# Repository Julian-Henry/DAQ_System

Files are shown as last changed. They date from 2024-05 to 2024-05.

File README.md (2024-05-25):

# DAQ_System

# Project Showcase Link
https://eecs.engineering.oregonstate.edu/project-showcase/projects/?id=z2oxjPZD8s8oi1AW

# Project Overview
The purpose of the personal data acquisition prototype project is to design a data recorder prototype for a general consumer target market. This prototype was designed to be used with a go-kart. Sensors can be connected to the data recorder in a modular fashion. Sensor modules were developed on custom-designed PCBs that utilize STM32 microcontrollers. Each microcontroller sends data to a database hosted on a Raspberry Pi. The data can then be outputted to the user through an intuitive UI. The firmware for the microcontrollers was developed using the RUST programming language. The database used SQLite. The UI was made using the EGUI framework in RUST. Some notable achievements include the UI and firmware development using Rust, a cutting-edge secure programming language, and the modularity of the system which allows for a variety of sensor configurations based on the user's preferences. Key challenges revolved around the creation of custom STM32-based PCBs, suggesting one key area for future improvement.

## System setup guide

Materials: 
  - Raspberry Pi with monitor, keyboard, and mouse. Make sure Its micro SD card has more than 8GB of space

  - RS485 CAN Hat

  - “Sensor modules” 

.

Steps:

1. Use the RS485 CAN Hat on the Pi. Connect sensor modules.

2. Flash code to the Nucleo dev boards that are in charge of the sensors (files in the nucleo_firmware directory).

3. Set up the CAN Hat on the Pi:

  // Open the Raspberry Pi terminal and run the following commands:
  wget https://github.com/joan2937/lg/archive/master.zip 
  unzip master.zip
  cd lg-master
  sudo make install
  
  sudo apt-get update
  sudo apt-get install python-serial
  sudo pip install python-can 
    //if it gives an error, run: rm /usr/lib/python3.11/EXTERNALLY-MANAGED
  sudo nano /boot/config.txt
  //in the file, Modify/create:
  dtparam=spi=on
  dtoverlay=mcp2515-can0,oscillator=12000000,interrupt=25,spimaxfrequency=2000000

  sudo reboot  //NOTE: you have to have the CAN hat connected before the Pi reboots
  
  //Finally, test that it knows the CAN is there:
  	dmesg | grep -i '\(can\|spi\)'

4. Copy the daq_gui_1 & logger_code directories to the Pi

5. Run the pi_can.py file in the logger_code directory to start the communication. You should see the data being sent in the terminal if it is working.

6. Go to the daq_gui_1 directory and run the daq_gui code (Use cargo run --release if it doesn’t work the normal way). It will take a long time to run the first time.

7. Done. It should work!

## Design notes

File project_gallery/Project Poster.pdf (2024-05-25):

C O L L E G E O F E N G I N E E R I N G | | E l e c t r i c a l E n g i n e e r i n g a n d C o m p u t e r S c i e n c e E C E . 0 4
| PERSONAL DATA ACQUISITION SYSTEM

# SYSTEM EXPLANATION

- Sensor modules can be easily swapped and connected to the system
- Sensors modules communicate with the logger using CAN bus protocol
- Developed sensor modules include ADC and accelerometer modules
- One sensor module features an industry-standard sensor connector (mikroBUS ), enabling easy integration with several hundred commerciallyavailable sensor modules
- The logger uses a Raspberry Pi to store data into a local SQL database and serve the UI to the user
- The UI allows the user to visualize and configure data from their custom sensor setup

# ENGINEERING REQUIREMENTS

- Easy to Understand - 9 out of 10 users will configure the sensors and afterwards report "The configuration process was easy.“
- Mobile - The system will operate normally for at least 1 hour on a single charge.
- Modular - The system will operate normally after having the sensor subsystem pulled against the logger subsystem with at least 5lbs of force.
- Precise - The system will output data with a resolution of at least 8 bits
- Sample Rate - The system will output data at least at 100HZ for analog voltage and acceleration data and at least 5Hz for GPS data.
- Storage - The system will store an hours worth of data collected by the system.
- User Feedback - The system will display data on the UI that updates according to the state of the sensors within 30 seconds of the real-world sensor state change.
- Works with Mikroe Sensors - The system will include at least 1 “mikroBUS” connection that will work with at least 1 Mikroe product.

# Real-time data feedback from modular sensor system

# TEAM MEMBERS

From left to right:

- Julian Henry - henryju@oregonstate.edu

PCB design, UI development

- Jaxon Young - youngjax@oregonstate.edu

Rust and CAN expert, logger development

- Alex Gibson - gibsona2@oregonstate.edu

Firmware expert, ADC block development

- Chris Patton (not pictured) – chris@pattondynamics.com

Owner of Patton Dynamics LLC

# SUMMARY

The Personal Data Acquisition System is a user-friendly device that allows real-time data collection and visualization from a range of sensors. The system’s modular design allows users to easily connect various sensor modules to the central data logger. Users can view and configure the collected data via a simple user interface. The system is powered by an internal battery, enabling dynamic outdoor use. The design focuses on inclusivity and affordability, aiming to bridge the gap between expensive and complex data acquisition systems and inaccurate “hobbyist” systems.

# UI EXPLANATION

- User can select connected sensors
- User can configure data visualization for each connected sensor
- User can change data save period with slider
- User can adjust data display time frame
- User can manually clear data to save space
- Uses STM32F207ZGT microcontrollers to acquire data on the sensor modules.
- Sensor modules connect to the logger module through RJ-45 connectors and ethernet cables.
- Plug-and-play system only needs a cable connection to begin collecting data.

# SYSTEM IMPLEMENTATION

# MIKROE SENSOR INTEGRATION

- Mikroe Click Sensors are compact add-on
boards that interface with systems via a mikroBUS socket
- The socket supports communication and power as specified by the mikroBUS standard
- In our system, the inclusion of this socket enables quick integration of new sensors without extensive hardware modifications
- The image below shows our Mikroe Sensor Block in a case. Our custom PCB (purple) is connected to a Mikroe Click Sensor (green) through a mikroBUS socket

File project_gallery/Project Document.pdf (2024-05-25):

# Personal Data Acquisition Prototype

Alex Gibson
Julian Henry
Jaxon Young

## Table of Contents

## Executive Summary

Our project aimed to bridge the gap between professional data collection and everyday users by providing a user-friendly yet precise data acquisition system. While existing solutions serve professionals well, they often lack user-friendliness for the average consumer. Conversely, consumer-friendly options are scarce, and tend to be lower-end devices that do not return specific, accurate data. Our goal was to provide a professional-grade data collection device that the common user can easily set up and use. Some data that could be desired include position, speed, acceleration, displacement, and rotation.

Our device utilized a modular design, with the ability to interchange sensors based on the application. We used STM32 microcontrollers that communicated to a Raspberry Pi via Ethernet cables using the CAN Bus communication protocol. The Raspberry Pi served dual roles, both hosting a database for sensor data storage and serving a user interface for sensor configuration and data visualization. Key sensors integrated into the system include GPS, an ADC for strain gauges, and a block with a mikroBUS™ interface that allowed any Mikroe Click Sensor to be used with the system with minimal reconfiguration.

The project was developed throughout the 2023/24 school year. Fall term was used for planning and prototyping, winter term was used for developing the system, and spring term was used to fix the last-minute issues that came up and present the final design.

As of now, we have successfully developed a functional prototype. Achievements include implementing a modular design, integrating STM32 microcontrollers, and developing a user-friendly UI. Challenges included mastering Rust and EGUI for UI development and custom PCB design complexities.

The top next steps for future development include reworking the custom PCB designs for the sensor modules to reduce reliance on external microcontroller boards, and to enhance UI functionality and aesthetics. Additionally, ensuring backup components and prioritizing environmental sustainability and user safety remain critical considerations for future development.

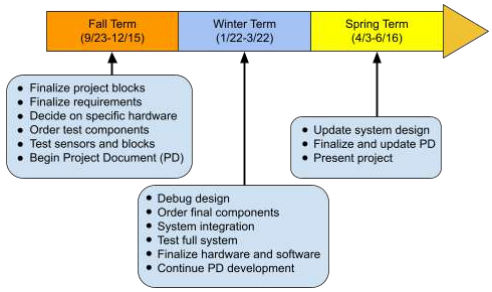
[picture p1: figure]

## Section 1: Project Overview

The purpose of this document is to give a description of the project by outlining the key features of the personal data acquisition prototype, describe the protocols used by the team for communication, explain where this project fits into the current product market, and to give a timeline for the development of the project. This section of the document outlines the project by giving an overview of the different features of the system and by describing how the team will go about designing the system.

### 1.1 Description

The purpose of the personal data acquisition prototype project is to design a data recorder prototype for a general consumer target market. The prototype will be designed to be used with a go-kart. Sensors will be connected to the data recorder in a modular fashion. These sensors will be developed on custom-designed PCBs that interface with STM32 microcontrollers. Each microcontroller will send data to a Raspberry Pi that transmits data to a database. This data can then be viewed visually by the user through a UI that supports data recording and configuration of the sensors. An STM32 microcontroller will be chosen for interfacing with the sensors, the firmware for the microcontrollers will be developed using the RUST programming language, the database will use SQLite, and the GUI will be made using the EGUI framework in RUST.

### 1.2 Team Contacts and Protocols

This section includes contact information for all team members. This section also contains a table showing our team protocols for communicating with each other and our project partner.

TABLE I
Team Contacts
Name | Email | Role
Alex Gibson | gibsona2@oregonstate.edu | Microcontroller Design
Julian Henry | henryju@oregonstate.edu | Treasurer, PCB Design
Jaxon Young | youngjax@oregonstate.edu | Database, Circuit Design

TABLE II
Protocols
Area | Protocol | Standard
Meeting | Due to busy scheduling, our team at this time does not have a standard meeting time. However, we will make an effort to meet each week when time permits and meet with our project partner on Tuesdays at 3:30pm via Zoom/ Discord | Google Doc notes to discuss topics on the table. Use of the website When2meet in order to find a time when our group can collectively meet.

Contact/ Communication | Team uses SMS and Discord to keep in contact. | Daily updates on progress.
Record/ Data Keeping | Team records meeting outcome and plans for next meeting on shared Google Doc | After each meeting, record the summary. Write down plans for the next meeting and what to be done beforehand.

### 1.2.1 Diversity, Equity, and Inclusion Statement

Our team will value everyone's ideas and will treat each other with respect. In our design, we will do our best to use language and visuals that are inclusive and understandable to everyone, creating a useful system for people from diverse backgrounds. We will collaborate closely and communicate openly to achieve these goals.

### 1.2.2 Communication Analysis

Communication with the project partner will happen primarily through Discord. Weekly check-in meetings will be conducted through Zoom. The project partner would like us to communicate what we will be working on, in enough detail that they understand what we are attempting to do and how we plan to do it. This level of communication will be especially important around our work relating to Rust, Embassy, and connection to their existing system of wireless communication to be used for the project, as they have more experiences with these topics and can offer assistance. There will also be a project GitHub that will contain all project information for the project partner to see at their convenience.

### 1.3 Gap Analysis

The purpose of this project is to fill the need for a cheap, accessible data collection tool for sport vehicles such as mountain bikes and go-karts. This project will provide a method for non-technical people to collect and understand the performance data of their activities. We will design this project to work with a go-kart, but leave open the option of customization so it could be redesigned for use with other vehicles with similar characteristics in the future.
The end users of this project will be individuals from various age groups and skill levels with an interest in sports vehicles. These users may not have extensive technical knowledge but are interested in either improving their performance or gaining insights into their activities. Currently, we are aiming for the cost of the system itself to be around $300. There are currently two main brands that provide data acquisition systems for go-karting: Alfano and AiM. Alfano data acquisition systems cost from 455€ to 855€ (approximately $487 to $915) [1]. AiM Kart Data Logger Systems cost from £470 to £520 (approximately $577 to $639) [2]. Thus, our system would open the market of high-functioning data acquisition devices to people of lower socioeconomic status.
By providing a simple and customizable solution, this project aims to cater to the needs of our end users and enable them to collect and analyze performance data without the complexity and cost barriers associated with existing tools in the market.

### 1.4 Timeline and Task List

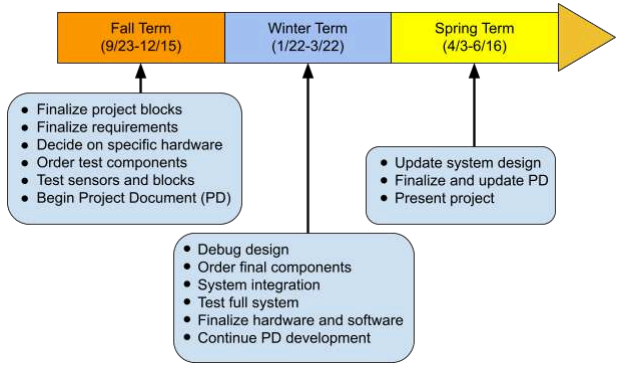
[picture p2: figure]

Fig. 1. Project Timeline

TABLE III
Project Task List
Task List | Impact Risk | Expected Hours | Week Due | Champion | Actual Hours
Draft Project Document section 1 | 3 | 9 | 3 | Alex | 9
Finalize system requirements | 10 | 12 | 4 | Jaxon | 15
Decide what sensors to use | 10 | 5 | 5 | Julian | 3
Decide on a microcontroller | 8 | 4 | 5 | Alex | 5
Determine power requirements | 8 | 3 | 5 | Jaxon | 3
Finalize project blocks | 5 | 4 | 5 | Julian | 10
Draft Project Document section 2 | 3 | 9 | 6 | Alex | 9
Finalize Project Document section 1 & 2 | 2 | 4 | 8 | Jaxon | 4
Draft Project Document section 3 & 5 | 5 | 10 | 9 | Julian | 13
Learn and practice Rust | 9 | 5 | 10 | Alex | 8

Research components | 8 | 6 | 11 | Jaxon | 6
Finalize block Interfaces | 9 | 9 | 12 | Julian | 9
Prototype first block | 9 | 15 | 12 | Alex | 4
Draft ADC and GPS block validations | 7 | 8 | 13 | Jaxon | 10
Draft Mikroe Sensor and Power block validations | 7 | 8 | 13 | Julian | 10
Draft UI and Logger block validations | 7 | 8 | 13 | Alex | 10
Prototype sensor, logger, and database communication | 7 | 6 | 13 | Jaxon | 20
Develop UI | 9 | 10 | 14 | Julian | 20
Verify first blocks | 8 | 12 | 15 | Alex | 15
Revise system architecture | 10 | 15 | 16 | Jaxon | 12
Research communication protocols | 8 | 8 | 17 | Julian | 12
Block Verification: Block 1 & 2 | 7 | 10 | 18 | Alex | 20
Update Project document | 4 | 4 | 19 | Jaxon | 23
Finalize PCBs and order | 9 | 10 | 20 | Julian | 22
Order final components | 8 | 5 | 20 | Alex | 22
Provide evidence for system verification | 7 | 4 | 20 | Jaxon | 10
Assemble blocks | 10 | 15 | 20 | Julian | 10
Test entire system | 10 | 20 | 20 | Alex | 10
Finalize executive summary | 1 | 2 | 30 | Jaxon | 1
Finalize project documentation | 2 | 12 | 30 | Julian | 4

### 1.5 References

[1] “Alfano Shop,” alfano.com, https://www.alfano.com/en/shop/ (accessed Jan. 21, 2024).
[2] “Kart - AIM Technologies,” aimtechnologies.com, https://www.aimtechnologies.com/kart/ (accessed Jan. 21, 2024).

### 1.6 Revision Table

TABLE IV
Section 1 Revision Table
5/10/2024 | Julian Henry: Updated task list for final submission
3/8/2024 | Team: Updated task list
1/21/2024 | Julian Henry: Revised section 1 using instructor feedback
12/4/2023 | Julian Henry: Revised section 1 using feedback from the WK8 Project Document assignment
11/05/2023 | Julian Henry, Alex Gibson: Revised section 1 using feedback from the first submission
10/22/2023 | Julian Henry: Proofread document
10/20/2023 | Jaxon Young: Drafted executive summary and section 1.2 Alex Gibson: Drafted project overview
10/19/2023 | Julian Henry: Drafted sections 1.2.1, 1.2.2, 1.3, and 1.4 Alex Gibson: Drafted section 1.1
10/16/2023 | Jaxon Young: Initial Document Creation. Section 1 outline created

## 2. Impacts and Risks

### 2.1 Design Impact Statement

### 2.1.1 Introduction

The personal data acquisition prototype is a modular data recorder used to take measurements such as GPS position and output them to a user through a user interface (UI). The UI will read the data from a database that will also be used to allow the user to record and store data. The goal of the design is to create a user-friendly modular data recorder for the general public. Although the device is not intended to have one specific application, the prototype will be designed so that it can be tested using a go-kart.

The purpose of this section is to report on the impacts that the personal data acquisition prototype could have on the public and the environment. Along with this, since engineers hold an important responsibility to consider the impacts of their designs, this section presents possible solutions for some of these negative impacts. This section does this by describing the impacts on public health, safety, and welfare, the cultural and social impacts related to the people creating the components of the device and the data privacy of those who are using it, the environmental impacts of materials used in electronics when they are not properly disposed of, and the economic impacts that the device could have on the data acquisition market for general applications as well as for go-kart specific applications.

### 2.1.2 Public Health, Safety, and Welfare Impacts

### 2.1.2.1 Risks of Battery-Powered Electronics

This device poses a risk to public safety by using batteries in the design. This is an issue because lithium batteries can fail, resulting in chemical and combustion reactions [1]. The main causes for such failures are damage to the batteries and improper charging methods. Some examples of how these batteries can become damaged are through physical damage such as dropping or puncturing the batteries and through environmental damage such as using them in high-temperature environments or charging them in below-freezing temperatures [1]. Along with this, the batteries shall be charged by following the manufacturer’s instructions on charging to avoid issues such as overcharging [1]. To avoid these issues, the product will be designed to avoid damage to the batteries by placing them inside an enclosure to reduce the risk of physical damage. Along with this, a charger in compliance with the manufacturer's instructions shall be included as well as information for the user on how to properly charge the device and what environments it can be used in.

### 2.1.2.2 Risk of Injury Due to Improper Application Installation

This device will be used to collect data in outdoor applications such as on a go-kart, mountain bike, or snowboard. Since this device will feature multiple modular sensor modules connected by cables to a main module, cables could possibly become tangled in mechanical components, resulting in the user crashing and injuring themselves. Thus, it is important that these cables do not get in the way of the moving components of a go-kart or mountain bike. One way to reduce this risk is to make sure all cable connections are resistant to vibrations. Vibrations can cause connectors to loosen or become damaged [2]. Along with this, instructions will be provided to the user explaining how to properly secure the device for their chosen application.

### 2.1.3 Cultural and Social Impacts

### 2.1.3.1 Material Sourcing Considerations

Our design is composed almost entirely of semiconductors and electronic components. Unfortunately, the conditions for tech factory workers are often not the best. Workers may be exposed to toxic chemicals, sustain injuries from machines, work long hours for insufficient pay, be forced to live in substandard housing, and more [3]. To mitigate the negative social and cultural impact of our design, we aim to source components from companies that prioritize their workers' well-being. While identifying the best companies for this can be challenging, a review of global working conditions in 2019 revealed that “the shortest average hours of work per week are found in North America and Europe and Central Asia, particularly in Northern, Southern and Western Europe” [4].
Thus, the project will prioritize the utilization of components sourced from factories in North America, Europe, or Central Asia.

### 2.1.3.2 Data Privacy and Security Considerations

Our design relies on Wi-Fi transmission to transmit data throughout the system. Inadequate safeguards could result in breaches of data, potentially causing harm to users and reducing trust in the technology. Data transmitted over Wi-Fi without any encryption or password protection is completely open and can be read by third parties as long as they are within range of the signal. According to data from the NTIA Internet Use Survey, “73 percent of Internet-using households in 2019 had significant concerns about online privacy and security risks, and 35 percent said such worries led them to hold back from some online activities” [5]. Thus, to limit the negative social and cultural impact of our design, we will implement a Wi-Fi security protocol. Wi-Fi security protocols such as Wired Equivalent Privacy (WEP), Wi-Fi Protected Access (WPA), Wi-Fi Protected Access 2 (WPA 2), or Wi-Fi Protected Access 3 (WPA 3) would keep the transmitted data hidden and block hackers from our network [6]. This step would help to create a system with which users can confidently engage, knowing that their data is secure and their privacy is protected.

### 2.1.4 Environmental Impacts

### 2.1.4.1 E-waste

Our design will incorporate various electronics to ensure proper operation. As the system ages, its electronics will fail and eventually need to be thrown out. This is known as electronic waste (e-waste). E-waste contains many toxic components such as lead, mercury, flame retardants, and lithium [7]. If not properly disposed of, these toxic components can contaminate surrounding groundwater and soil [7]. This can damage the surrounding ecosystem and wildlife. In addition to toxic components, e-waste also contains valuable materials such as gold, copper, silver, iron, and zinc [8]. Salvaging these precious materials can affect the environment both positively and negatively. If these materials are properly recycled, materials may have the chance to be reused in the next design, reducing the amount of e-waste produced overall. However, improper recycling of e-waste can negatively impact the environment. Many developed and developing countries employ improper standards for recycling e-waste. Open-air burning and acid baths are sometimes used to extract valuable materials, creating toxic substances that can leach into the environment [9]. To help combat these issues, our design will focus on increasing the lifespan of our electronic devices in various ways such as ensuring proper storage and use conditions according to manufacturers, implementing robust enclosures when in use, and including extensive documentation so users know how to care for the components. In addition, we will provide information on the proper disposal of e-waste.

### 2.1.5 Economic Factors

### 2.1.5.1 Affordability Compared to Current Solutions

The primary economic factor for our system will be the setup required to ensure the proper operation of sensors and other system components. After the initial setup and testing, the system will primarily be composed of readily available components and small custom PCBs. Currently, we are aiming for the cost of the system itself to be around $300. There are currently two main brands that provide data acquisition systems for go-karting: Alfano and AiM. Alfano data acquisition systems cost from 455€ to 855€ (approximately $487 to $915) [10]. AiM Kart Data Logger Systems cost from £470 to £520 (approximately $577 to $639) [11]. Thus, our system would open the market of high-functioning data acquisition devices to people of lower socioeconomic status.

### 5.2 Impact on Economic Equality in the Go-Kart Racing Community

Our system will provide a more affordable data logger system for go-kart enthusiasts of lower socioeconomic status or more casual / newer go-karters who may not want to burn several hundred dollars on an auxiliary piece of equipment. Additionally, it may also help make go-kart racing more equitable for competitors from different economic backgrounds. The purpose of a go-kart data acquisition system is to provide real-time kart monitoring information to the driver which can make them faster and more consistent [12]. If all other differences are ignored, a racer with a data acquisition system will likely do better in a race than a racer without, due to the quality of information they are able to receive. The high price point of current data acquisition systems means that racers with more capital are more able to reap the benefits of a data acquisition system than racers with a tighter budget. Our lower-range price point would then hold the potential to make go-kart racing more equitable in this way.

### 2.1.6 Conclusion

Engineers hold a pivotal role in addressing societal needs and desires. As professionals in this field, it is imperative that we carefully consider the impact of our products across various domains, ensuring a comprehensive evaluation while aligning with the ultimate objectives of the project. By acknowledging the potential impacts of our design, we can make the proper adjustments in our design and build process in order to reduce the negative impacts and risk factors. Our areas of impact and possible solutions include
- Lithium Battery Fire/Explosion
- Follow manufacturers’ charging instructions
- Enclose battery to protect from physical damage or extreme temperature
- Privacy/Security Risk
- Wi-Fi Security Protocols
- Material Sourcing
- Sourcing materials from companies that focus on factory worker well-being
- Readily Available, Affordable
- Electronic Waste
- Increase lifespan of electronics by properly enclosing to avoid condensation and adverse conditions
- Provide instructions on proper disposal

### 2.2 Risks

This section will contain a risk assessment table, TABLE V, listing several risks the team has identified that could impact the project’s success. Each risk has a risk ID, a description, category, and probability rating (low, med, high), as well as an impact score (low, med, high) showing how detrimental to our project’s success the risk would be if it happened, and an action plan containing steps to reduce the risks’ impact.

TABLE V
Risk Assessment Table
Risk ID | Risk Description | Risk Category | Risk Probability | Risk Impact | Action Plan
R1 | Incompatible interface | Technical | Low | High | - Plan system interfaces exhaustively
R2 | Team member needs to take time for personal matters unexpectedly | Organizational | Med | Med | - Gather time-sensitive materials team member had - List work team member had to complete and make a plan to delay/adjust deadlines - Redistribute work for expected time of absence. If it is unreasonable, contact course instructor
R3 | Battery catches fire | Safety | Low | High | - Make sure to have a fire extinguisher nearby when working with batteries - Use extinguisher to prevent further ignition
R4 | Component delays (from Chinese New Year, etc.) | Schedule | Low | Med | - Note estimated shipping time when ordering components - Order components two weeks before they are needed, accounting for the estimated shipping time
R5 | Component goes out of stock | Technical | High | Med | - Plan backup components
R6 | Go-kart breaks the system | Safety | Med | High | - Carefully plan out how the system will be attached - Maintain up-to-date documentation and notes so system can be rebuilt quickly - Order duplicate components if economically viable
R7 | Weather prevents testing | Environmental | Med | Med | - Look at the weather forecast before testing
R8 | Issues with third-party APIs (changes in functionality, downtime, etc.) | Technical | Low | High | - Use a well-known API - Keep a backup in mind in case a switch is necessary - Be prepared to implement code at the register level if an API becomes unusable.

R9 Poor time estimation
for tasks
Schedule | High | Med | - Double all time estimates
- Consult with partner to create realistic time estimates
- Create personal deadlines ahead of actual deadline

### 2.3 File Links 2.3.1 References (IEEE)

[1] OSHA, “Preventing Fire and/or Explosion Injury from Small and Wearable Lithium Battery Powered Devices,” osha.gov. https://www.osha.gov/sites/default/files/publications/shib011819.pdf (accessed Nov. 8, 2023).
[2] “The Importance of Anti-Vibration Features in Industrial Electrical Connectors,” energy5.com. https://energy5.com/the-importance-of-anti-vibration-features-in-industrial-electrical-connectors (accessed Nov. 8, 2023).
[3] M. Blanding, “How China is screwing over its poisoned factory workers,” Wired, https://www.wired.com/2015/04/inside-chinese-factories/ (accessed Nov. 9, 2023).
[4] Eurofound and International Labour Organization, “Working conditions in a global perspective,” Publications Office of the European Union, and International Labour Organization, https://www.ilo.org/wcmsp5/groups/public/---dgreports/---dcomm/---publ/documents/publication/wcms_696174.pdf (accessed Nov. 8, 2023).
[5] M. Cao, “Nearly three-fourths of online households continue to have digital privacy and security concerns,” National Telecommunications and Information Administration, https://www.ntia.gov/blog/2021/nearly-three-fourths-online-households-continue-have-digital-privacy-and-security-conc erns (https://www.ntia.gov/blog/2021/nearly-three-fourths-online-households-continue-have-digital-privacy-and-security-concerns) (accessed Nov. 9, 2023).
[6] D. Ghimiray, “Wi-Fi Security: WEP vs WPA or WPA2,” Avast https://www.avast.com/c-wep-vs-wpa-or-wpa2 (accessed Nov. 9, 2023).
[7] “E-Waste & its negative effects on the environment,” elytus, https://elytus.com/blog/e-waste-and-its-negative-effects-on-the-environment.html (accessed Nov. 9, 2023).
[8] “Cleaning up electronic waste (e-waste),” epa.gov, https://www.epa.gov/international-cooperation/cleaning-electronic-waste-e-waste (accessed Nov. 9, 2023).

[9] S. Manikandan, D. Inbakandan, C. Valli Nachiyar, S. Karthick Raja Namasivayam, "Towards sustainable metal recovery from e-waste: A mini review," Sustainable Chemistry for the Environment, https://doi.org/10.1016/j.scenv.2023.100001 (accessed Nov. 9, 2023).
[10] “Alfano Shop,” alfano.com, https://www.alfano.com/en/shop/ (accessed Nov. 9, 2023).
[11] “Kart - AIM Technologies,” aimtechnologies.com, https://www.aimtechnologies.com/kart/ (accessed Nov. 9, 2023).
[12] “Karting Data & Timing,” competitionmotorsport.com, https://competitionmotorsport.com/collections/karting-data-timing (accessed Nov. 9, 2023).

### 2.3.2 File Links

[13] https://drive.google.com/file/d/1RbJMouxU02F9vibak4BKAWVEbUblvC5h/view?usp=sharing
The content for section 2.2 was mostly created during lecture time. This link shows an image of the document created at that point.

### 2.4 Revision Table

TABLE VI
Section 2 Revision Table
4/21/24 | Julian Henry: Updated section 2 with Design Impact Assessment content
11/19/23 | Revised the introduction according to feedback from Rachel Cate, Lane Hartless, and Neha Suryadevara Revised section 3.1 according to feedback from Neha Suryadevara Revised section 4.1 according to feedback from Cameron Hicks and Neha Suryadevara Changed instances of “could” and “should” to “shall” or “will” according to feedback from Cameron Hicks Revised the conclusion according to feedback from Neha Suryadevara
11/19/2023 | Julian Henry, Alex Gibson: Revised section 2 using feedback from the draft submission
11/12/23 | Reformatted the references section according to feedback from Rachel Cate and Frank Wong
11/09/2023 | Julian Henry: Section 2 updated with file links section and minor updates
11/05/2023 | Julian Henry: Section 2 outline created, section 2.2 drafted

## 3. Top-Level Architecture

### 3.1 Block Diagram

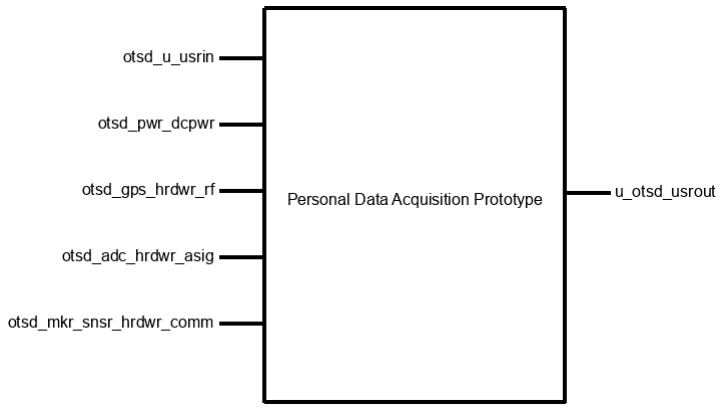
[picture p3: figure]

Fig. 2. Black Box Image

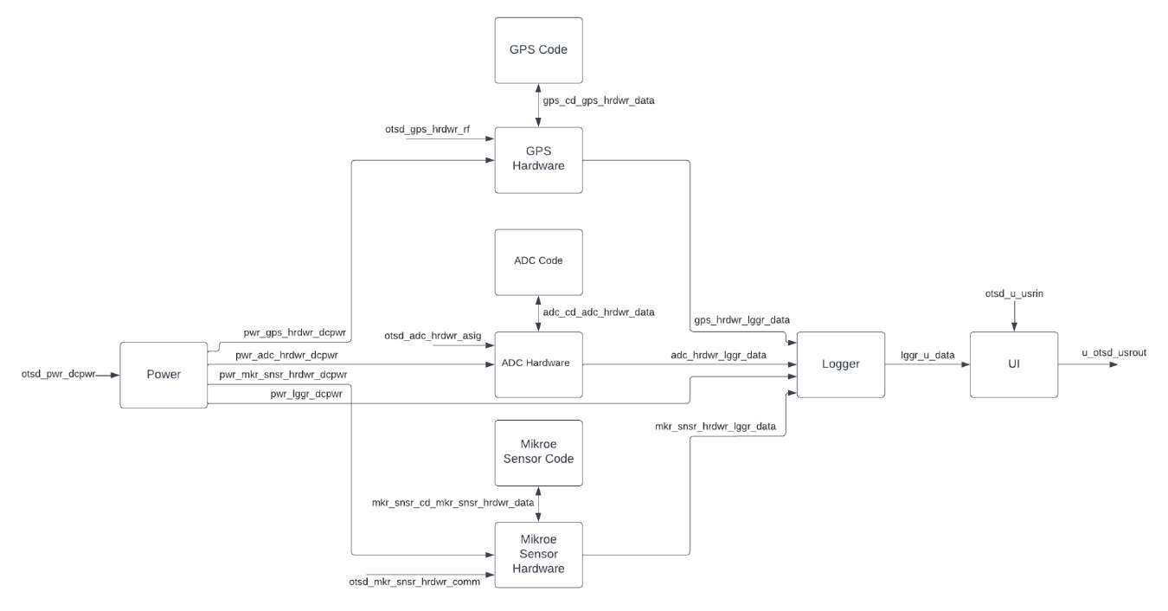
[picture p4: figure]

Fig. 3. System Block Diagram [9]

### 3.2 Block Descriptions

This section gives a short description of what each block from figure 3 in section 3.1 accomplishes for the system and what it contains.

### 3.2.1 ADC Hardware

The ADC Hardware Block is used by the system to measure analog voltage values. It satisfies the system’s modularity requirement due to it connecting to the logger module through an RS45 cable, the precision requirement by taking 24-bit data samples, and the sample rate requirement by including an ADC that can sample at a rate significantly higher than 100Hz. The block features an ADC, a microcontroller, a programmer connection, a linear regulator, a CAN bus transceiver, and interface connectors. The ADC will be able to read analog voltage values from a strain gauge that connects to the block. These voltage values can then be sent to the microcontroller through SPI communication protocol. The microcontroller can then send these values to the logger block using CAN bus communication.

### 3.2.2 ADC Code

The ADC Code block is used by the system to provide the microcontroller code necessary for the ADC hardware block to function correctly. The code works by first configuring the ADC with the correct settings before taking analog voltage
measurements at a rate of 100Hz. After each measurement, it sends the data over the CAN bus interface which is then received by the logger module. The code is uploaded to the microcontroller using a Serial Wire Debug interface (SWD) provided by an ST-Link programmer device.

### 3.2.3 GPS Hardware

The GPS Block is used by the system to measure position values. It satisfies the system’s modularity requirement due to it connecting to the logger module through an RS45 cable, the precision requirement by taking 8-bit position measurements, and the sample rate requirement by including a GPS that can sample at a rate of at least 5Hz. The block features a NEO-M9N GPS, a microcontroller, a programmer connection, a linear regulator, a CAN bus transceiver, and interface connectors. The GPS will be able to read RF signals from satellites that give the position and transmission time of the satellite. This information is then used to calculate the position of the GPS which is then sent to the microcontroller through UART communication protocol. The microcontroller can then send these values to the logger block using CAN bus communication.

### 3.2.4 GPS Code

The GPS Code block is used by the system to provide the microcontroller code necessary for the GPS hardware block to function correctly. The code works by first configuring the GPS with the correct settings before taking position values at a rate of 5Hz. After each measurement, it sends the data over the CAN bus interface which is then received by the logger module. The code is uploaded to the microcontroller using a Serial Wire Debug interface (SWD) provided by an ST-Link programmer device.

### 3.2.5 Mikroe Sensor Hardware

The Mikroe Sensor Hardware Block features a MikroBUS(TM) connection interface, a microcontroller, a programming interface, a voltage regulator, and a CAN transceiver. This block will allow the system to use any Mikroe Click sensor board with minimal configuration. This will increase the functionality of the system while not requiring the design and assembly of additional custom sensor boards.

The MikroBUS(TM) interface will be used to connect any Mikroe Click sensor board to our system. This will greatly increase the potential functionality of our system by enabling it to use any of the 525 current Mikroe click sensor boards available on Mikroe's website [3]. The firmware for the connected Click Sensor board can be sent to the microcontroller using the programming port. The connected Mikroe Click sensor board can then send data to the microcontroller, which works to update the logger block with the sensor data using CAN bus communication through the CAN transceiver.

### 3.2.6 Mikroe Sensor Code

The Mikroe Sensor Code block is used by the system to provide the microcontroller code necessary for the Mikroe Sensor hardware block to function correctly. The code works by first configuring the Mikroe Sensor with the correct settings before taking measurements at a rate of 100Hz. After each measurement, it sends the data over the CAN bus interface which is then received by the logger module. The code is uploaded to the microcontroller using a Serial Wire Debug interface (SWD) provided by an ST-Link programmer device.

### 3.2.7 Logger

The logger will collect data from the sensors and store them into a database. In this application, a Raspberry PI 4B will be used as the logger device. The Raspberry PI 4B will be powered ideally at 5V however, can be operated at a minimum voltage of 4.8V and a maximum of 5.2V. An RS485 CAN Hat will interface with the desired sensor modules using CAN communication. Using low-speed CAN mode, the logger will record incoming sensor data at a maximum rate of 100Kbit/sec. The logger will take in incoming sensor messages ranging from 8 bits to 24 bits depending on the sensor module. Incoming GPS and Mikroe sensor messages will be in the size of 8-bits while the ADC sensor will send 24-bit messages. A local database located on the pi will store the incoming sensor data using SQLite, making a query after every new message sent. The logger will continue to read and store sensor data until reaching a specified time. Although most of the system will be programmed in rust, the PI will be programmed in python.

### 3.2.8 UI

The UI module will help the user interface with the logger and sensors of the system. Programmed in rust using the EGUI library, the UI will fetch data from the logger module's database and manipulate data based on the user’s preference. The user will be able to select which sensors they would like to view/manipulate the data of and specify the amount of time they would like the logger to record data for. During data collection, the user will have two options on how they would like to view the incoming recorded data. An option to output data into a table or graph will be given. The user can also specify the period of time they would like to view of the data.

### 3.2.9 Power

This block will provide power to the entire system including the GPS block, the ADC block, the Mikroe sensor block, and the logger block. The power block will be rechargeable and able to support the system with all blocks using their peak current for an hour on one charge. This means that it must have a charge capacity greater than the sum of all the peak currents required by every block multiplied by one hour. According to the block interfaces, each of the three sensor blocks has a peak input current of 170mA, and the logger has a peak of 1.75A. This gives: (170mA + 170mA + 170mA + 1.75A)*(1 hour) = 2.26A*1h = 2.26 Ah, or 2260 mAh. To accomplish this, the power block features a commercially available portable charger.

### 3.3 Interface Definitions

TABLE VII
Block interface table
Name | Properties
otsd_u_usrin | ● Type: three interactable checkboxes lined up 1x3 to record member variable ● Type: interactable "slider" bar to record integer ● Usability: understandable by 9/10 users
otsd_pwr_dcpwr | ● Inominal: 1A ● Ipeak: 1.75A ● Vmax: 5.25V ● Vmin: 4.75V
otsd_gps_hrdwr_rf | ● Datarate: 50bits/sec ● Messages: messages contain the position and time of the GPS satellites ● Protocol: NMEA-0183
otsd_adc_hrdwr_asig | ● Other: 24 bit signal measurement resolution ● Vmax: 3.3V ● Vrange: 0-3.3V
otsd_mkr_snsr_hrdwr_comm | ● Datarate: 100kbps or more ● Messages: Data from the Mikroe Click sensor board that is connected ● Other: MikroBUS-style Socket
u_otsd_usrout | ● Other: UI updates at least every 30 seconds ● Type: Graph of data vs time ● Usability: Human-readable numeric output used to give specific values
pwr_gps_hrdwr_dcpwr | ● Inominal: 33mA ● Ipeak: 170mA ● Vmax: 5.2V ● Vmin: 4.8V

pwr_adc_hrdwr_dcpwr | ● Inominal: 33mA ● Ipeak: 170mA ● Vmax: 5.2V ● Vmin: 4.8V
pwr_lggr_dcpwr | ● Inominal: 1A ● Ipeak: 1.25A ● Vmax: 5.2V ● Vmin: 4.8V
pwr_mkr_snsr_hrdwr_dcpwr | ● Inominal: 33mA ● Ipeak: 170mA ● Vmax: 5.2V ● Vmin: 4.8V
gps_hrdwr_lggr_data | ● Datarate: 100Kbit/sec CAN Bus speed ● Messages: 8 bits ● Protocol: CAN bus
adc_hrdwr_lggr_data | ● Datarate: 100Kbit/sec CAN bus speed ● Messages: 24 bits ● Protocol: CAN bus
lggr_u_data | ● Messages: data from all sensor modules ● Messages: float type ● Other: SQLite Query
mkr_snsr_cd_mkr_snsr_hrdw r_data | ● Messages: Binary code file ● Other: Pin header connection ● Protocol: Serial Wire Debug
mkr_snsr_hrdwr_lggr_data | ● Datarate: 100Kbit/sec CAN Bus speed ● Messages: 8 bits ● Protocol: CAN bus
adc_cd_adc_hrdwr_data | ● Messages: Binary code file ● Other: Pin header connection ● Protocol: Serial Wire Debug
gps_cd_gps_hrdwr_data | ● Messages: Binary code file ● Other: Pin header connection

- Protocol: Serial Wire Debug

### 3.4 References and File Links 3.4.1 References (IEEE)

[1] Analog Devices, “AD7124-8 (Rev. F),” analog.com, https://www.analog.com/media/en/technical-documentation/data-sheets/ad7124-8. pdf, (https://www.analog.com/media/en/technical-documentation/data-sheets/ad7124-8.pdf) (accessed Nov. 28, 2023).
[2] u-blox, “NEO-M9N Integration Manual,” u-bloxcom, https://content.u-blox.com/sites/default/files/NEO-M9N_Integrationmanual_UBX-1 9014286.pdf, (https://content.u-blox.com/sites/default/files/NEO-M9N_Integrationmanual_UBX-19014286.pdf) (accessed Nov. 28, 2023).
[3] “Sensors: Click boards,” mikroe.com, https://www.mikroe.com/click/sensors (accessed Dec. 3, 2023).
[4] “Portable Charger Info Page,” Amazon, https://www.amazon.com/gp/product/B07PG6C5C7 (accessed Dec. 4, 2023).
[5] “Standard specifications - MIKROE,” MikroBus Standard specifications, https://download.mikroe.com/documents/standards/mikrobus/mikrobus-standard-s pecification-v200.pdf (https://download.mikroe.com/documents/standards/mikrobus/mikrobus-standard-specification-v200.pdf) (accessed Dec. 5, 2023).
[6] “DATASHEET - Raspberry Pi,” Raspberry Pi 4 Model B Datasheet, https://datasheets.raspberrypi.com/rpi4/raspberry-pi-4-datasheet.pdf (accessed Dec. 5, 2023).
[7] T. Thurium, “Three easy ways to brick a Raspberry Pi,” Twilio Blog, https://www.twilio.com/blog/3-ways-brick-raspberry-pi (accessed Dec. 4, 2023).
[8] KVASER, “The CAN Bus Protocol Tutorial,” kvaser.com, https://www.kvaser.com/can-protocol-tutorial/, (accessed Nov. 28, 2023).

### 3.4.2 File Links

[9]
https://drive.google.com/file/d/1paBB9K00yNNS22RuKPmCooDzpVnGpm-5/view?usp=sharing (https://drive.google.com/file/d/1paBB9K00yNNS22RuKPmCooDzpVnGpm-5/view?usp=sharing)
This links to a copy of the original document used to create figure 3.

### 3.5 Revision Table

TABLE VI
Section 3 Revision Table
4/21/2024 | Julian Henry: Updated section with descriptions from portal
3/10/2024 | Team: updated interface definitions
3/8/2024 | Team: Updated block diagrams and descriptions

12/4/2023 | Julian Henry: Filled out section 3.3 from project portal, updated several references Alex Gibson: Added references to section 3.3
12/3/2023 | Alex Gibson: Added sources for 3.2.1 and 3.2.2
11/30/2023 | Julian Henry: Section 3.1 filled in
11/29/2023 | Julian Henry: Section 3 outline created

## 4. Block Validations

This section starts with the Block Validations that your team members have completed. There needs to be a section for each block in your project.

### 4.1 ADC Hardware

### 4.1.1 Description

The ADC Hardware Block is used by the system to measure analog voltage values. It satisfies the system’s modularity requirement due to it connecting to the logger module through an RS45 cable, the precision requirement by taking 24-bit data samples, and the sample rate requirement by including an ADC that can sample at a rate significantly higher than 100Hz. The block features an ADC, a microcontroller, a programmer connection, a linear regulator, a CAN bus transceiver, and interface connectors. The ADC will be able to read analog voltage values from a strain gauge that connects to the block. These voltage values can then be sent to the microcontroller through SPI communication protocol. The microcontroller can then send these values to the logger block using CAN bus communication.

### 4.1.2 Design

This section describes the design of the ADC sensor hardware block. It includes a black box diagram showing the interfaces of the block. These interfaces are the voltages connected to the ADC, the DC power used to power the module, the programmer connection used to upload code to the microcontroller, and the CAN bus communication line used to communicate with the logger module. This section also includes schematic diagrams for the hardware design. These diagrams cover the microcontroller used to interface with the ADC and CAN bus, linear regulator used to convert the 4.8-5.2V power input to a 3.3V output, CAN transceiver used to convert the digital data signal to an analog differential pair signal, the ADC used to convert external analog voltages to 24-bit digital values, and the connectors used for all of the interfaces.

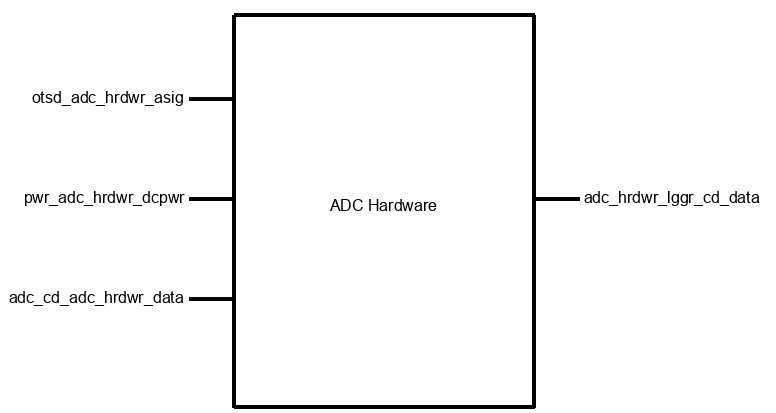
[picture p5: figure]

Fig. 1. Black box image of the ADC Hardware block

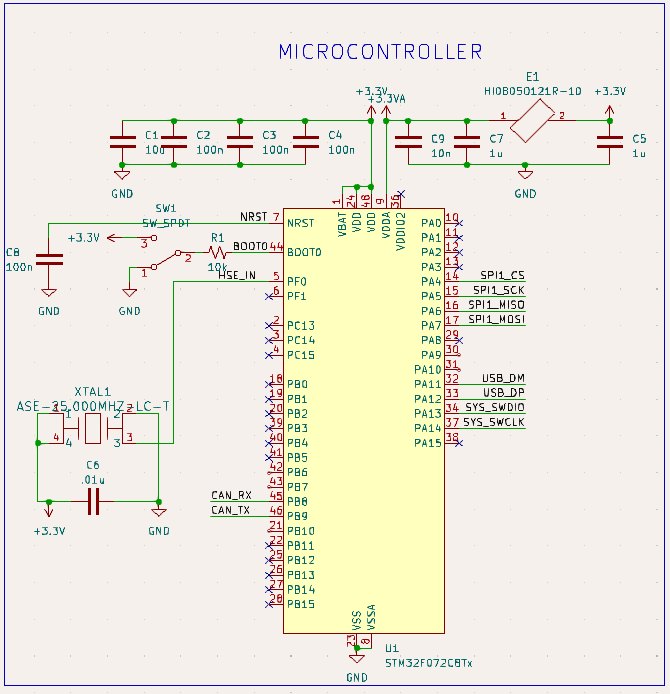
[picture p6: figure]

Fig. 2. ADC Hardware Block Microcontroller Schematic

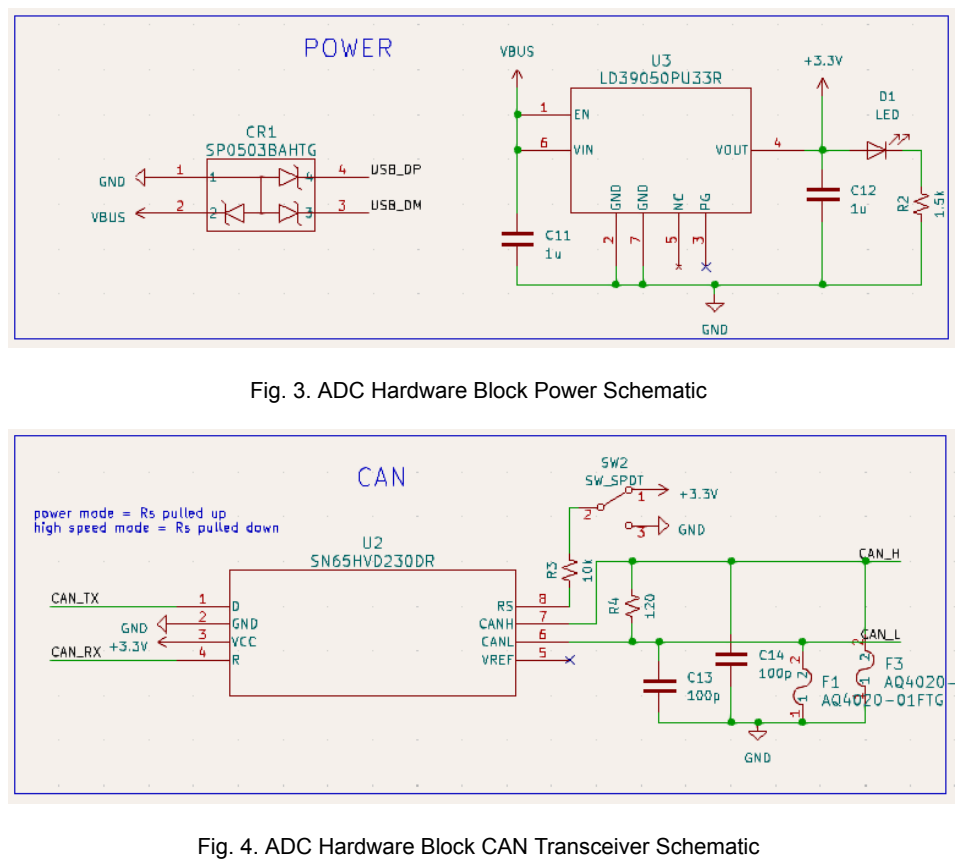
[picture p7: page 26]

Fig. 3. ADC Hardware Block Power Schematic

Fig. 4. ADC Hardware Block CAN Transceiver Schematic

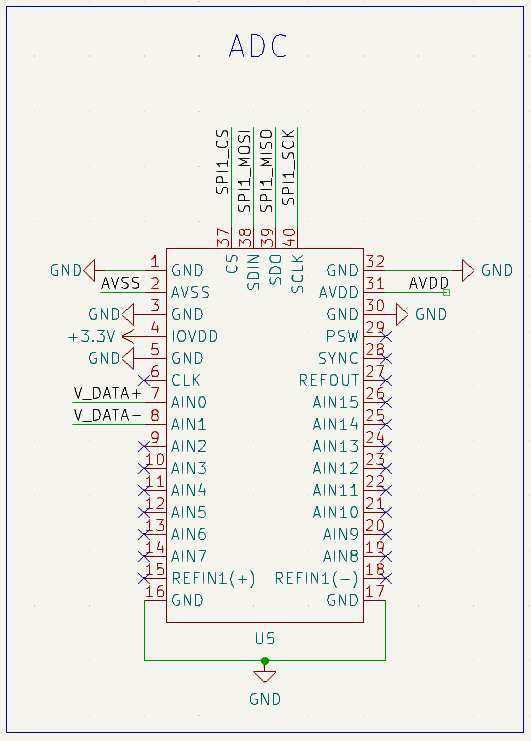
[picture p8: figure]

Fig. 5. ADC Hardware Block ADC Daughter Board

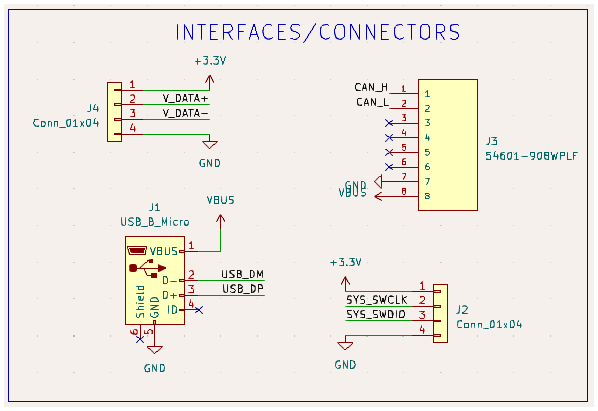
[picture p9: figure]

Fig. 6. ADC Hardware Block Interfaces / Connectors Schematic

### 4.1.3 General Validation

The ADC Hardware Block needs to be able to sample analog voltage values between 0 and 3.3 volts with a minimum resolution of 24-bits per sample and output that data through CAN bus protocol to the logger block. Along with this, due to the sampling rate requirement for the system, the ADC must take these measurements at a minimum sampling rate of 100Hz. Lastly, the ADC block must also be able to do these operations with a voltage input between 4.8 and 5.2 volts.

The Microcontroller schematic shown in figure 2 features an STM32F072C8T6TR microcontroller. This specific microcontroller was chosen due to it having the necessary peripheral support for all of the devices used in all of the sensor blocks for the entire system. These peripherals are I2C, SPI, UART, CAN, USB, and pulse width modulation. This means that the same microcontroller can be integrated into each of the 3 sensor hardware designs. Along with this, the microcontroller was also chosen due to it being low cost and featuring an IC package with a low amount of pins that are easily solderable. The microcontroller circuit design features a 3.3 volt connection provided by the LD39050PU33R which is used to power the microcontroller. Each power input pin is connected to a 100nF decoupling capacitor to filter out noise as recommended by the hardware development document for the microcontroller [1]. A ferrite bead is used to isolate noise from the 3.3V source for the VDDA pin. This design for isolating VDDA from the other power input pins was found in a STM32 board design video guide [2]. The reset pin (NRST) is connected to a 100n capacitor to prevent the microcontroller from resetting due to noise. A 25 MHz crystal oscillator is used as the clock source for the microcontroller. According to the hardware development document, a 4 to 32 MHz external oscillator should be used for the design [1]. A decoupling capacitor is connected between the 3.3V and GND pin on the oscillator to filter noise. The tri-state pin on the oscillator is connected to 3.3V in order to enable the oscillator’s output [3]. The boot mode pin was connected to a switch so that it could be pulled high or low for either boot option. Lastly, pins PB8 and PB9 are used for the can peripheral, pins PA4 - PA7 are used for the SPI peripheral, PA11 and PA12 are used for the USB peripheral, and PA13 and PA14 are used for the programmer interface [4].

The power schematic shown in figure 3 features an LD39050PU33R linear regulator and an SP0503BAHTG TVS diode block used to protect the USB connection against electrostatic discharge. The power for the system works where a 5.0V input called VBUS is connected to the input pin of the linear regulator which then outputs 3.3V. VBUS is provided by either a micro-USB connection or a RJ45 connection. The application information for the linear regulator recommends connecting 1uF capacitors to the Vin and Vout inputs [5]. Along with this, Vin is also connected to the enable pin in order to enable the output of the IC. Lastly, an LED is attached to Vout to give a visual indication that power is being output by the linear regulator.

The CAN transceiver schematic shown in figure 4 features an SN65HVD230DR transceiver used to convert digital CAN data from the microcontroller to a differential pair data output. As specified in the datasheet for the transceiver, data being sent from the microcontroller is connected to the D pin and data being received is connected to the R pin. The differential pair data is output on pins CANH and CANL which are connected by a 120 ohm termination resistor to improve signal quality [6] [7]. According to the device datasheet, the RS pin should be pulled high for power mode or pulled low for high speed mode [7]. In the schematic, a switch is used so that either mode can be used. Lastly, capacitors and TVS diodes are used on the CANH and CANL connections to reduce noise and protect against large surges in voltage.

The ADC schematic shown in figure 5 features an EVAL-AD7124-8-PMDZ board which is a breakout board for the AD7124-8 ADC. This board will be used as a daughter board to the ADC hardware by connecting it to the PCB for the ADC hardware circuit. The SPI connection from the microcontroller is used to communicate with the ADC [8]. The ADC is powered by the same 3.3V source as the microcontroller, and this voltage is used to power the analog output pins AVDD and AVSS which are used as the reference voltage for the device [9]. Lastly, the ADC uses pins AIN0 and AIN1 as the positive and negative inputs for the measured voltage.

The interface/connectors schematic shown in figure 6 features a micro-USB connector used for data transfer and powering the linear regulator, a RJ45 connector used to transfer the CAN data and provide power when connected to the logger module, a strain gauge connector for the analog voltage input measured by the ADC, and pin headers used for a JTAG programming connection.

While this circuit is designed with the intention of using CAN bus protocol in power mode, an alternate solution using high speed mode is possible by using the switch to connect the RS pin on the transceiver to GND and desoldering the 120 ohm resistor. Another alternate solution for this design would be to connect LEDs to some of the extra GPIO pins for debugging purposes. Lastly, an alternative solution for the ADC would be to use a different reference voltage from the 3.3V powering the IC in order to increase the voltage range that the ADC can measure. Along with this, more AIN pins on the ADC could be used to measure multiple analog voltage inputs at once.

### 4.1.4 Interface Validation

Table I
ADC Hardware Block interface validation table
Interface
Property

Why is this interface this value? Why do you know that your design details for this block above meet or exceed each property?

otsd_adc_hrdwr_asig : Input

Other: 24 bit signal measurement resolution | The AD7124-8 was chosen as the ADC to be used on the board. This ADC has a 24-bit resolution on its measurements [8]. | The general description section on page 4 of the datasheet for the AD7124-8 states that “the device contains a low noise, 24-bit Σ-Δ analog-to-digital converter (ADC)” [8].
Vmax: 3.3V | The ADC will have its analog reference voltage (AVDD) set to the 3.3V output from the linear regulator. | Linear regulator will output 3.3V when powered by 5.0V [5].
Vrange: 0-3.3V | The ADC will have AVDD set to the 3.3V output from the microcontroller. | Analog voltage range is 0V to AVDD for bipolar mode as described on page 48 of the datsheet [8].

pwr_adc_hrdwr_dcpwr : Input

Inominal: 33mA | Nominal current of microcontroller with a system clock of 60MHz. | The microcontroller will typically draw 26 mA at 25 ℃ and 39 mA at 85 ℃ [4]. Since the ADC has a significantly lower current draw, it can be estimated that the nominal current will be between 25 and 39 mA [8].
Ipeak: 170mA | Peak power input current of the microcontroller and ADC chip being used [4] [8]. | Microcontroller and ADC will draw at most 170mA [4] [8]. Since the microcontroller and ADC are not being fully utilized, the current draw will be less than this maximum value.

Vmax: 5.2V | Ideal input voltage is 5.0V so this value allows for some variance without going too far out of range. | Max operating input voltage for the linear regulator is 5.5V as described on page 6 of the datasheet, meaning 5.2V is in range [5].
Vmin: 4.8V | Ideal input voltage is 5.0V so this value allows for some variance without going too far out of range. | Since the linear regulator is described on page 6 of the datasheet as outputting a value of Vin - 0.3 with a minimum Vin value of 1.5V, a value of 4.8 will satisfy both conditions above to output 3.3V [5].

adc_hrdwr_lggr_cd_data : Output

Datarate: 100Kbit/sec CAN bus speed | This speed was chosen because the design will be using a CAN bus connection in low-speed mode to improve signal quality. CAN bus configured for low-speed mode has a maximum data rate of 125 Kbit/sec [6]. | According to page 5 of the SN65HVD23 transceiver datasheet, low-speed mode is configured by pulling RS to 3.3V [7].
Messages: 24 bits of data | A CAN bus transmission will occur after each ADC sample. | ADC samples are 24-bits of data [8].
Protocol: CAN bus | CAN bus was chosen as the protocol to communicate between the logger block and the ADC block because of its application in automotive systems and because our project partner is familiar with the protocol. | The chosen microcontroller supports CAN bus peripherals on the PB8 and PB9 pins [4]. The CAN_RX and CAN_TX signals from these two pins are connected to the CAN transceiver which converts the digital values sent and received by these pins to differential pair signals [7].

adc_cd_adc_hrdwr_data : Bi-directional

Messages: Binary code file | Code must be compiled down to machine code to be run on the microcontroller. | Binary instructions stored in flash memory are used to control the microcontroller [10].
Other: Pin header connection | Pin headers were chosen for an easy connection method using an ST-Link programmer. | St-Link connector uses pin connections to program the microcontroller [11].
Protocol: Serial Wire Debug | SWD is used by the ST-Link programmer. | SWD sends a data stream over two wires to program ARM CPUs such as STM32 microcontrollers [12].

### 4.1.5 Verification Process

1. Connect jumper wires between the adc_cd_adc_hrdwr_data interface and the ST-Link programmer connected to a computer, then program the microcontroller with the ADC block testbench firmware.
2. Disconnect the programmer and connect the ADC block’s adc_hrdwr_lggr_cd_data CAN bus connection to the adc_hrdwr_lggr_cd_data CAN bus connection on the raspberry-pi.
3. Connect the ADC block’s pwr_adc_hrdwr_dcpwr input to a 4.8V power source.
4. Run the ADC block testbench python script on the raspberry pi.
5. Connect the otsd_adc_hrdwr_asig input to GND and confirm that the raspberry-pi is receiving a 3 byte sequence of 0x00 0x00 0x00 on the
adc_hrdwr_lggr_cd_data interface.
6. Connect the otsd_adc_hrdwr_asig input to 3.3V and confirm that the raspberry-pi is receiving a 3 byte sequence of approximately 0xFF 0xFF 0xFF on the adc_hrdwr_lggr_cd_data interface.
7. Confirm in the code of both the ADC microcontroller and the raspberry-pi that both are configuring the CAN bus protocol to run at 100Kb/sec.
8. Change the pwr_adc_dcpwr input to 5.2V and repeat steps 5-7.

### 4.1.6 References and File Links

[1] STMicroelectronics, “Getting started with STM32F0x1/x2/x8 hardware development,” st.com,
https://www.st.com/resource/en/application_note/an4080-getting-started-with-stm3 2f0x1x2x8-hardware-development-stmicroelectronics.pdf, (https://www.st.com/resource/en/application_note/an4080-getting-started-with-stm32f0x1x2x8-hardware-development-stmicroelectronics.pdf) (accessed Mar 3, 2024).
[2] Phil’s Lab, “KiCad 6 STM32 PCB Design Full Tutorial - Phil's Lab #65,” youtube.com,
https://www.youtube.com/watch?v=aVUqaB0IMh4&ab_channel=Phil%E2%80%99 sLab, (https://www.youtube.com/watch?v=aVUqaB0IMh4&ab_channel=Phil%E2%80%99sLab) (accessed Mar. 6, 2024).
[3] Abracon, “3.3V CMOS Compatible 3.2 x 2.5mm SMD Crystal Oscillator,” abracon.com, https://abracon.com/Oscillators/ASEseries.pdf, (accessed Mar. 6, 2024).
[4] STMicroelectronics, “STM32F072x8 STM32F072xB,” st.com, https://www.st.com/content/ccc/resource/technical/document/datasheet/cd/46/43/83/22/d3/40/c8/DM00090510.pdf/files/DM00090510.pdf/jcr:content/translations/en. DM00090510.pdf, (https://www.st.com/content/ccc/resource/technical/document/datasheet/cd/46/43/83/22/d3/40/c8/DM00090510.pdf/files/DM00090510.pdf/jcr:content/translations/en.D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) (accessed Dec. 6, 2023).
[5] STMicroelectronics, “LD39050,” st.com, https://www.st.com/content/ccc/resource/technical/document/datasheet/12/43/cc/93/21/f6/41/66/CD00227527.pdf/files/CD00227527.pdf/jcr:content/translations/en.C D00227527.pdf, (https://www.st.com/content/ccc/resource/technical/document/datasheet/12/43/cc/93/21/f6/41/66/CD00227527.pdf/files/CD00227527.pdf/jcr:content/translations/en.C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) (accessed Jan. 27, 2024).

[6] KVASER, “The CAN Bus Protocol Tutorial,” kvaser.com, https://www.kvaser.com/can-protocol-tutorial/, (accessed Nov. 28, 2023).
[7] Texas Instruments, “SN65HVD230DR,” ti.com, https://www.ti.com/lit/ds/symlink/sn65hvd230.pdf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 e.com%252F, (https://www.ti.com/lit/ds/symlink/sn65hvd230.pdf?HQS=dis-dk-null-digikeymode-dsf-pf-null-wwe&ts=1709546681296) (accessed Mar 4, 2024).
[8] Analog Devices, “AD7124-8 (Rev. F),” analog.com, https://www.analog.com/media/en/technical-documentation/data-sheets/ad7124-8. pdf, (https://www.analog.com/media/en/technical-documentation/data-sheets/ad7124-8.pdf) (accessed Nov. 28, 2023).
[9] Analog Devices, “EVAL-AD7124-8-PMDZ Overview,” wiki.analog.com, https://wiki.analog.com/resources/eval/user-guides/circuits-from-the-lab/eval-ad71 24-8-pmdz, (https://wiki.analog.com/resources/eval/user-guides/circuits-from-the-lab/eval-ad7124-8-pmdz) (accessed Mar. 6, 2024).
[10] STMicroelectronics, “STM32F0 series Cortex-M0 programming manual,” st.com, https://www.st.com/resource/en/programming_manual/pm0215-stm32f0-series-cor texm0-programming-manual-stmicroelectronics.pdf, (https://www.st.com/resource/en/programming_manual/pm0215-stm32f0-series-cortexm0-programming-manual-stmicroelectronics.pdf) (accessed Mar 4, 2024).
[11] Adafruit, “ST-Link STM8/STM32 v2 Compatible Programmer & Emulator,” adafruit.com, https://www.adafruit.com/product/2548, (accessed Mar 4, 2024).
[12] Silicon Labs, “Serial Wire Debug (SWD), https://community.silabs.com/s/article/serial-wire-debug-swd-x?language=en_US, community.silabs.com, (accessed Mar 4, 2024).

### 4.1.7 Revision Table

TABLE II
Subsection 4.1 Revision Table
3/6/2024 | Alexander Gibson: Updated section 4.1.1 with a statement about how the block contributes to the overall system, provided schematic diagrams in section 4.1.2, rewrote section 4.1.3 to discuss the new schematics, updated section 4.1.4 by adding a table label, including new interfaces and their properties, and fixing Vmin and Vmax values due to them being incorrectly switched, updated section 4.1.5 to prove all interfaces of the block, and updated section 4.1.6 with more datasheet links.
1/24/2023 | Alexander Gibson: Added intro paragraph to design section, updated interface names and values to match student portal, and modified interface validation to match changes in design choices.
12/6/2023 | Alexander Gibson: Filled out sections 4.1.1 through 4.1.7

### 4.2 ADC Code

### 4.2.1 Description

The ADC Code block is used by the system to provide the microcontroller code necessary for the ADC hardware block to function correctly. The code works by first configuring the ADC with the correct settings before taking analog voltage
measurements at a rate of 100Hz. After each measurement, it sends the data over the CAN bus interface which is then received by the logger module. The code is uploaded to the microcontroller using a Serial Wire Debug interface (SWD) provided by an ST-Link programmer device.

### 4.2.2 Design

This section provides a black box diagram and pseudocode to describe the functionality of the ADC Code block.

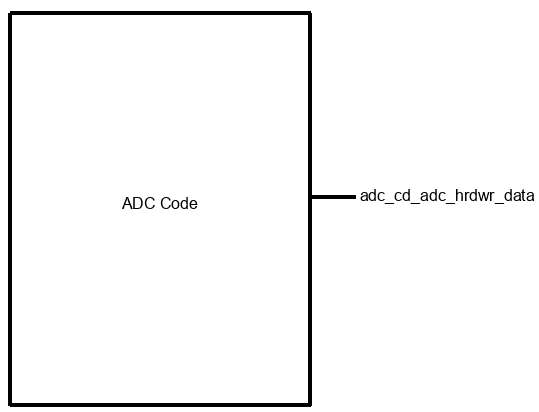
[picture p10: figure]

Fig. 1. Black box image of the ADC Code block Import libraries.
Bind interrupts for CAN bus peripheral.
Create objects for CAN bus and SPI connections.
Configure CAN object to use a bitrate of 100Kbps.
Configure SPI object to use a bitrate of 100Kbps, have an idle CLK level of high, and to capture data on second CLK transition. Initialize a data buffer to hold 3 bytes of data.

Reset the ADC using SPI communication
Configure the ADC through SPI to use its AVDD pin as the reference voltage to data measurements.
Loop
Read ADC voltage measurement.
Create a transfer frame for CAN communication protocol. Send the transfer frame to the CAN data bus.
Wait 10 ms.
end

Fig. 2. Pseudocode for the ADC Code block

### 4.2.3 General Validation

The ADC Code block needs to be able to take 24-bit analog voltage measurements at a rate of 100Hz and send them out over CAN bus. This code also needs to be able to be uploaded to an STM32F072C8T6TR microcontroller through a pin header connection using SWD.

Figure 2 from section 4.2.2 shows how this code will function. By using the embassy framework library, objects can be created for the SPI and CAN bus peripherals. These objects are first created by passing the correct pin values for their respective I/O pins, and any necessary interrupts used for their functionality. They are then configured to communicate at a rate of 100Kbps. According to the datasheet for the ADC, the SPI protocol used to communicate with it requires the CLK signal to be held high while idle and for data to be clocked on the second CLK transition [2]. In order to configure the ADC to use the AVDD pin as the reference voltage for measurements, register 0x19 needs to be set to 0x78 in order to set the correct reference. After this, the code infinitely loops by taking ADC measurements and sending them over can. It does this by using a 10 ms timer so that measurements can be taken at exactly 100Hz. The loop waits for the timer to complete before sending the read request value of 0x42 to the ADC. After receiving the data, it then outputs the data in a CAN transmission frame from the CAN_tx pin on the microcontroller. The timer is then reset and the loop repeats.

### 4.2.4 Interface Validation

Table I
ADC Code Block interface validation table
Interface
Property

Why is this interface this value? Why do you know that your design details for this block above meet or exceed each property?

adc_cd_adc_hrdwr_data : Bi-directional

Messages: Binary code file | Code must be compiled down to machine code to be run on the microcontroller. | Binary instructions stored in flash memory are used to control the microcontroller [3].
Other: Pin header connection | Pin headers were chosen for an easy connection method using an ST-Link programmer. | St-Link connector uses pin connections to program the microcontroller [4].
Protocol: Serial Wire Debug | SWD is used by the ST-Link programmer. | SDW sends a data stream over two wires to program ARM CPUs such as STM32 microcontrollers [5].

### 4.2.5 Verification Process

1. Connect the ST-link programmer between the computer and the pin headers of the adc_cd_adc_hrdwr_data interface.
2. Flash the code onto the microcontroller.
3. Connect the ADC hardware block to the logger block and confirm that the logger is receiving data.

### 4.2.6 References and File Links

[1] Embassy Project Contributors, “embassy_stm::can,” docs.embassy.dev, https://docs.embassy.dev/embassy-stm32/git/stm32f413rh/can/index.html, (accessed Dec. 6, 2023).
[2] Analog Devices, “AD7124-8 (Rev. F),” analog.com, https://www.analog.com/media/en/technical-documentation/data-sheets/ad7124-8. pdf, (https://www.analog.com/media/en/technical-documentation/data-sheets/ad7124-8.pdf) (accessed Nov. 28, 2023).
[3] STMicroelectronics, “STM32F0 series Cortex-M0 programming manual,” st.com, https://www.st.com/resource/en/programming_manual/pm0215-stm32f0-series-cor texm0-programming-manual-stmicroelectronics.pdf, (https://www.st.com/resource/en/programming_manual/pm0215-stm32f0-series-cortexm0-programming-manual-stmicroelectronics.pdf) (accessed Mar 4, 2024).
[4] Adafruit, “ST-Link STM8/STM32 v2 Compatible Programmer & Emulator,” adafruit.com, https://www.adafruit.com/product/2548, (accessed Mar 4, 2024).
[5] Silicon Labs, “Serial Wire Debug (SWD), https://community.silabs.com/s/article/serial-wire-debug-swd-x?language=en_US, community.silabs.com, (accessed Mar 4, 2024).

### 4.2.7 Revision Table

TABLE II
Subsection 4.2 Revision Table
3/8/2024 | Alexander Gibson: Created and filled out sections 4.2.1 - 4.2.7

### 4.3 GPS Block

### 4.3.1 Description

The GPS Block is used by the system to measure position values. It satisfies the system’s modularity requirement due to it connecting to the logger module through an RS45 cable, the precision requirement by taking 8-bit position measurements, and the sample rate requirement by including a GPS that can sample at a rate of at least 5Hz. The block features a NEO-M9N GPS, a microcontroller, a programmer connection, a linear regulator, a CAN bus transceiver, and interface connectors. The GPS will be able to read RF signals from satellites that give the position and transmission time of the satellite. This information is then used to calculate the position of the GPS which is then sent to the microcontroller through UART communication protocol. The microcontroller can then send these values to the logger block using CAN bus communication.

### 4.3.2 Design

This section describes the design of the GPS sensor hardware block. It includes a black box diagram showing the interfaces of the block. These interfaces are the RF satellite signals received by the GPS, the DC power used to power the module, the programmer connection used to upload code to the microcontroller, and the CAN bus communication line used to communicate with the logger module. This section also includes schematic diagrams for the hardware design. These diagrams cover the microcontroller used to interface with the GPS and CAN bus, linear regulator used to convert the 4.8-5.2V power input to a 3.3V output, CAN transceiver used to convert the digital data signal to an analog differential pair signal, the GPS used to receive position values, and the connectors used for all of the interfaces.

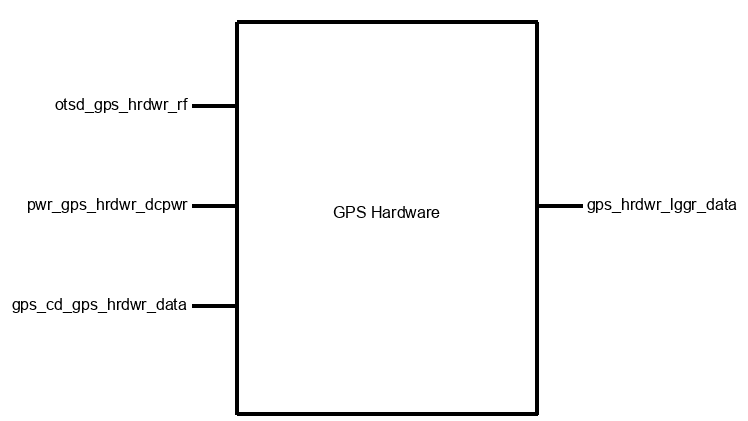
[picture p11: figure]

Fig. 1. Black box image of the block

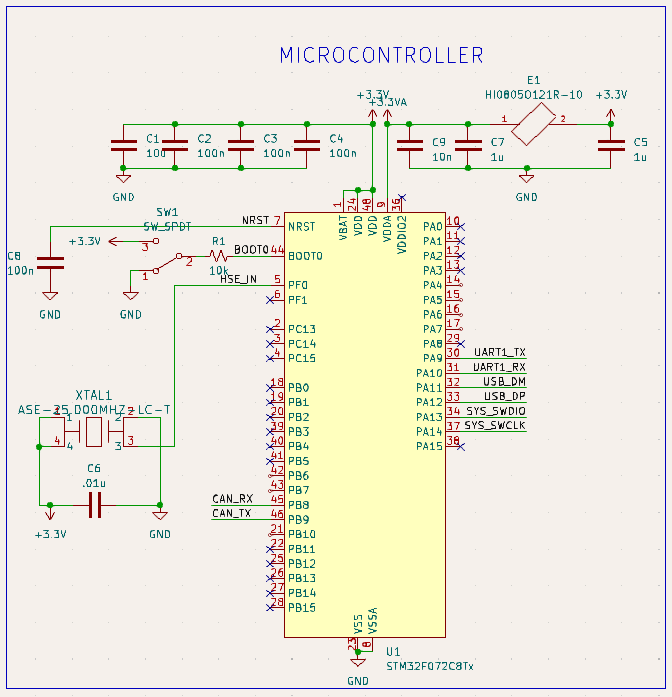
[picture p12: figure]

Fig. 2. GPS Hardware Block Microcontroller Schematic

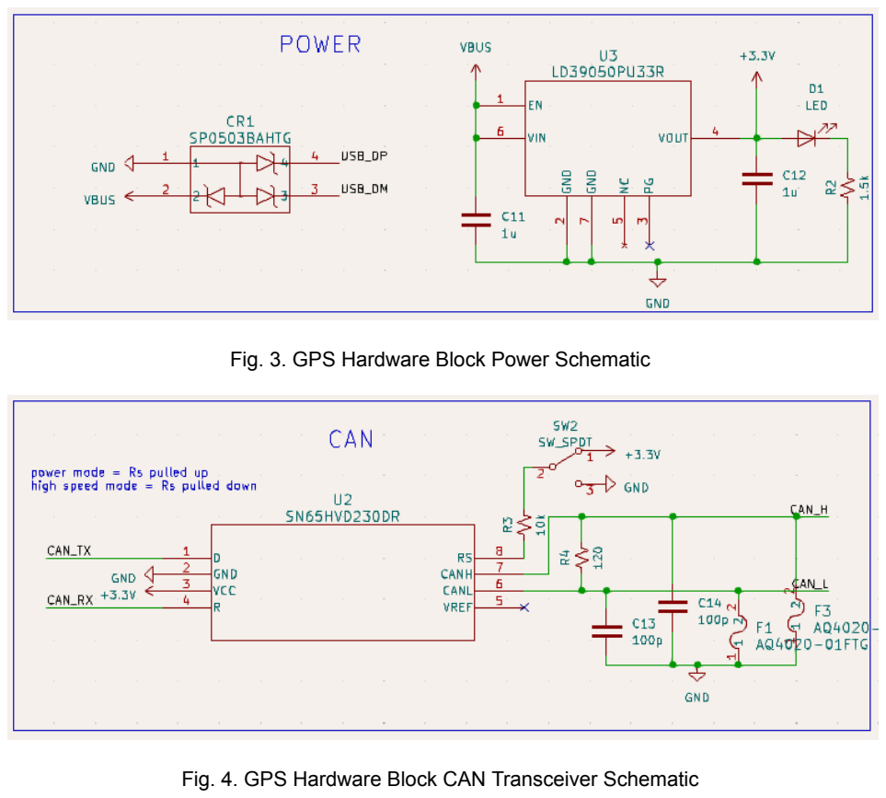
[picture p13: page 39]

Fig. 3. GPS Hardware Block Power Schematic

Fig. 4. GPS Hardware Block CAN Transceiver Schematic

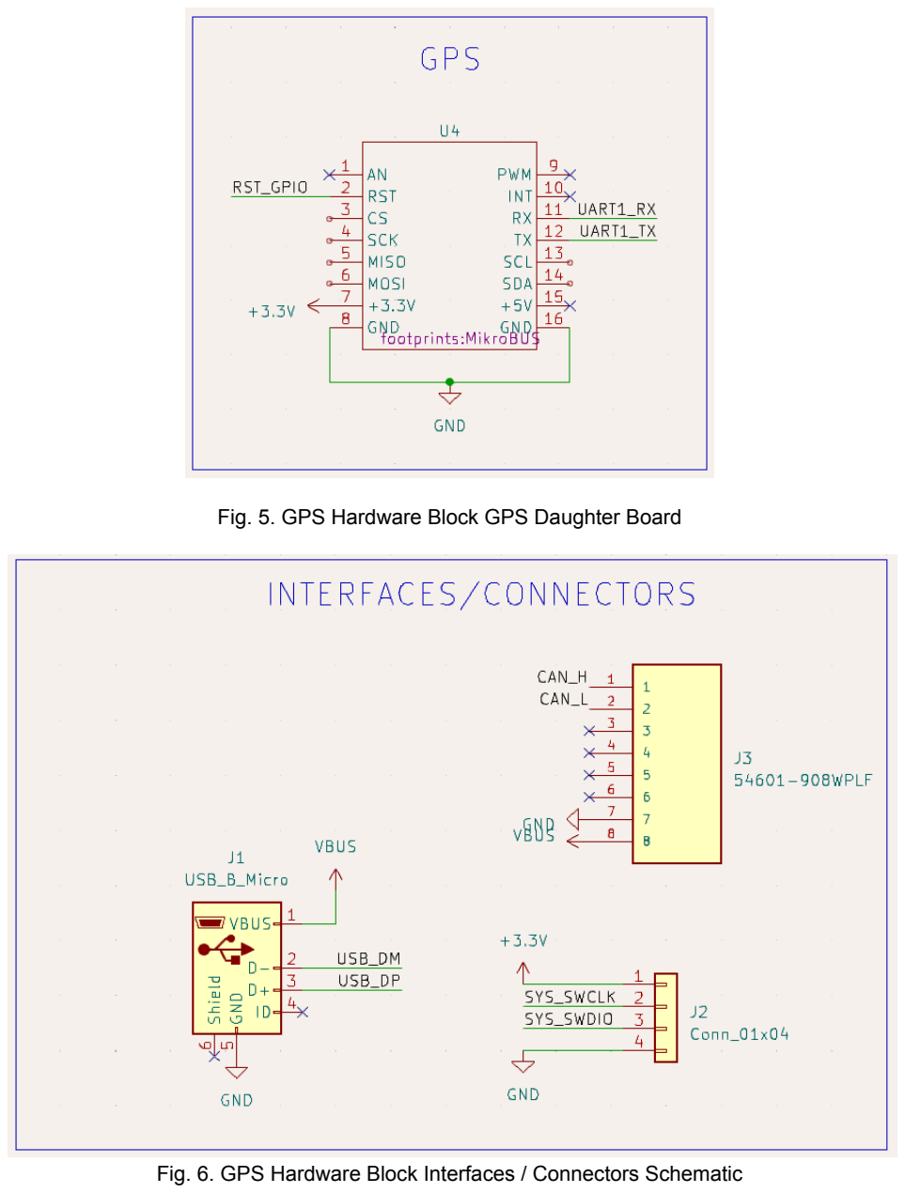
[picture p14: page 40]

Fig. 5. GPS Hardware Block GPS Daughter Board

Fig. 6. GPS Hardware Block Interfaces / Connectors Schematic

### 4.3.3 General Validation

The GPS Hardware Block needs to be able to take in RF signals from GPS satellites and calculate position measurements of at least 8-bits and output that data through CAN bus protocol to the logger block. Along with this, due to the sampling rate requirement for the system, the GPS must take these measurements at a minimum sampling rate of 5Hz. Lastly, the GPS block must also be able to do these operations with a voltage input between 4.8 and 5.2 volts.

The Microcontroller schematic shown in figure 2 features an STM32F072C8T6TR microcontroller. This specific microcontroller was chosen due to it having the necessary peripheral support for all of the devices used in all of the sensor blocks for the entire system. These peripherals are I2C, SPI, UART, CAN, USB, and pulse width modulation. This means that the same microcontroller can be integrated into each of the 3 sensor hardware designs. Along with this, the microcontroller was also chosen due to it being low cost and featuring an IC package with a low amount of pins that are easily solderable. The microcontroller circuit design features a 3.3 volt connection provided by the LD39050PU33R which is used to power the microcontroller. Each power input pin is connected to a 100nF decoupling capacitor to filter out noise as recommended by the hardware development document for the microcontroller [1]. A ferrite bead is used to isolate noise from the 3.3V source for the VDDA pin. This design for isolating VDDA from the other power input pins was found in a STM32 board design video guide [2]. The reset pin (NRST) is connected to a 100n capacitor to prevent the microcontroller from resetting due to noise. A 25 MHz crystal oscillator is used as the clock source for the microcontroller. According to the hardware development document, a 4 to 32 MHz external oscillator should be used for the design [1]. A decoupling capacitor is connected between the 3.3V and GND pin on the oscillator to filter noise. The tri-state pin on the oscillator is connected to 3.3V in order to enable the oscillator’s output [3]. The boot mode pin was connected to a switch so that it could be pulled high or low for either boot option. Lastly, pins PB8 and PB9 are used for the can peripheral, pins PA4 - PA7 are used for the SPI peripheral, PA11 and PA12 are used for the USB peripheral, and PA13 and PA14 are used for the programmer interface [4].

The power schematic shown in figure 3 features an LD39050PU33R linear regulator and an SP0503BAHTG TVS diode block used to protect the USB connection against electrostatic discharge. The power for the system works where a 5.0V input called VBUS is connected to the input pin of the linear regulator which then outputs 3.3V. VBUS is provided by either a micro-USB connection or a RJ45 connection. The application information for the linear regulator recommends connecting 1uF capacitors to the Vin and Vout inputs [5]. Along with this, Vin is also connected to the enable pin in order to enable the output of the IC. Lastly, an LED is attached to Vout to give a visual indication that power is being output by the linear regulator.

The CAN transceiver schematic shown in figure 4 features an SN65HVD230DR transceiver used to convert digital CAN data from the microcontroller to a differential pair data output. As specified in the datasheet for the transceiver, data being sent from the microcontroller is connected to the D pin and data being received is connected to the R pin. The differential pair data is output on pins CANH and CANL which are connected by a 120 ohm termination resistor to improve signal quality [6] [7]. According to the device datasheet, the RS pin should be pulled high for power mode or pulled low for high speed mode [7]. In the schematic, a switch is used so that either mode can be used. Lastly, capacitors and TVS diodes are used on the CANH and CANL connections to reduce noise and protect against large surges in voltage.

The GPS schematic shown in figure 5 features a GNSS 7 CLICK board which acts as a breakout board for the NEO-F9P GPS. This board will be used as a daughter board to the GPS hardware by connecting it to the PCB for the GPS hardware circuit. The UART connection from the microcontroller is used to communicate with the GPS [8]. The GPS is powered by the same 3.3V source as the microcontroller.

The interface/connectors schematic shown in figure 6 features a micro-USB connector used for data transfer and powering the linear regulator, a RJ45 connector used to transfer the CAN data and provide power when connected to the logger module, and pin headers used for a JTAG programming connection.

While this circuit is designed with the intention of using CAN bus protocol in power mode, an alternate solution using high speed mode is possible by using the switch to connect the RS pin on the transceiver to GND and desoldering the 120 ohm resistor. Another alternate solution for this design would be to connect LEDs to some of the extra GPIO pins for debugging purposes.

### 4.3.4 Interface Validation

Interface
Property

Why is this interface this value? Why do you know that your design details for this block above meet or exceed each property?

otsd_gps_hrdwr_rf : Input

Datarate: 50bits/sec | A 1500 bit data frame is sent from the satellite to the GPS chip over the course of 30 seconds [9]. | GPS chip receives data from GPS satellites [8].
Messages: messages contain the position and time of the GPS satellites | The GPS chip needs to know the position of the satellite and the time it initially sent the signal to use the amount of time that the signal traveled to find the chip’s position [10]. | NEO-M9N GPS chip is used in the design which calculates position based on the RF signals it receives from satellites.
Protocol: NMEA-0183 | This is the protocol used by GPS satellites to communicate with GPS chips [8]. | According to its datasheet, the NEO-M9N uses NMEA-0183 to communicate with satellites [8].

pwr_gps_hrdwr_dcpwr : Input

Inominal: 33mA Nominal current of microcontroller with a system clock of 60MHz.

The microcontroller will typically draw 26 mA at 25 ℃ and 39 mA at 85 ℃ [4]. Since the GPS has a significantly lower current draw, it

| | can be estimated that the nominal current will be between 25 and 39 mA [8].
Ipeak: 170mA | Peak power input current of the microcontroller and ADC chip being used [4] [8]. | Microcontroller and GPS will draw at most 170mA [4] [8]. Since the microcontroller and GPS are not being fully utilized, the current draw will be less than this maximum value.
Vmax: 5.2V | Ideal input voltage is 5.0V so this value allows for some variance without going too far out of range. | Max operating input voltage for the linear regulator is 5.5V as described on page 6 of the datasheet, meaning 5.2V is in range [5].
Vmin: 4.8V | Ideal input voltage is 5.0V so this value allows for some variance without going too far out of range. | Since the linear regulator is described on page 6 of the datasheet as outputting a value of Vin - 0.3 with a minimum Vin value of 1.5V, a value of 4.8 will satisfy both conditions above to output 3.3V [5].

gps_hrdwr_lggr_data : Output

Datarate: 100Kbit/sec CAN bus speed | This speed was chosen because the design will be using a CAN bus connection in low-speed mode to improve signal quality. CAN bus configured for low-speed mode has a maximum data rate of 125 Kbit/sec [6]. | According to page 5 of the SN65HVD23 transceiver datasheet, low-speed mode is configured by pulling RS to 3.3V [7].
Messages: 8 bits of data | A CAN bus transmission will occur after each GPS sample. | GPS samples are 8-bits of data [8].
Protocol: CAN bus | CAN bus was chosen as the protocol to communicate between the logger block and the GPS block because of its application in automotive systems and because our project partner is familiar with the protocol. | The chosen microcontroller supports CAN bus peripherals on the PB8 and PB9 pins [4]. The CAN_RX and CAN_TX signals from these two pins are connected to the CAN transceiver which converts the digital values sent and received by these pins to differential pair signals [7].

gps_cd_gps_hrdwr_data : Bi-directional

Messages: Binary code file | Code must be compiled down to machine code to be run on the microcontroller. | Binary instructions stored in flash memory are used to control the microcontroller [11].
Other: Pin header connection | Pin headers were chosen for an easy connection method using an ST-Link programmer. | St-Link connector uses pin connections to program the microcontroller [12].
Protocol: Serial Wire Debug | SWD is used by the ST-Link programmer. | SDW sends a data stream over two wires to program ARM CPUs such as STM32 microcontrollers [13].

### 4.3.5 Verification Process

1. Connect jumper wires between the gps_cd_gps_hrdwr_data interface and the ST-Link programmer connected to a computer, then program the microcontroller with the GPS block testbench firmware.
2. Disconnect the programmer and connect the GPS block’s gps_hrdwr_lggr_cd_data CAN bus connection to the gps_hrdwr_lggr_cd_data CAN bus connection on the raspberry-pi.
3. Connect the GPS block’s pwr_gps_hrdwr_dcpwr input to a 4.8V power source.
4. Run the GPS block testbench python script on the raspberry pi.
5. Confirm that the raspberry pi is receiving data values of at least 8-bits.
6. Confirm in the code of both the GPS microcontroller and the raspberry-pi that both are configuring the CAN bus protocol to run at 100Kb/sec.
7. Change the pwr_gps_dcpwr input to 5.2V and repeat steps 5-7.

### 4.3.6 References and File Links

[1] STMicroelectronics, “Getting started with STM32F0x1/x2/x8 hardware development,” st.com,
https://www.st.com/resource/en/application_note/an4080-getting-started-with-stm3 2f0x1x2x8-hardware-development-stmicroelectronics.pdf, (https://www.st.com/resource/en/application_note/an4080-getting-started-with-stm32f0x1x2x8-hardware-development-stmicroelectronics.pdf) (accessed Mar 3, 2024).
[2] Phil’s Lab, “KiCad 6 STM32 PCB Design Full Tutorial - Phil's Lab #65,” youtube.com,
https://www.youtube.com/watch?v=aVUqaB0IMh4&ab_channel=Phil%E2%80%99 sLab, (https://www.youtube.com/watch?v=aVUqaB0IMh4&ab_channel=Phil%E2%80%99sLab) (accessed Mar. 6, 2024).
[3] Abracon, “3.3V CMOS Compatible 3.2 x 2.5mm SMD Crystal Oscillator,” abracon.com, https://abracon.com/Oscillators/ASEseries.pdf, (accessed Mar. 6, 2024).
[4] STMicroelectronics, “STM32F072x8 STM32F072xB,” st.com, https://www.st.com/content/ccc/resource/technical/document/datasheet/cd/46/43/83/22/d3/40/c8/DM00090510.pdf/files/DM00090510.pdf/jcr:content/translations/en. DM00090510.pdf, (https://www.st.com/content/ccc/resource/technical/document/datasheet/cd/46/43/83/22/d3/40/c8/DM00090510.pdf/files/DM00090510.pdf/jcr:content/translations/en.D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) (accessed Dec. 6, 2023).

[5] STMicroelectronics, “LD39050,” st.com, https://www.st.com/content/ccc/resource/technical/document/datasheet/12/43/cc/93/21/f6/41/66/CD00227527.pdf/files/CD00227527.pdf/jcr:content/translations/en.C D00227527.pdf, (https://www.st.com/content/ccc/resource/technical/document/datasheet/12/43/cc/93/21/f6/41/66/CD00227527.pdf/files/CD00227527.pdf/jcr:content/translations/en.C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) (accessed Jan. 27, 2024).
[6] KVASER, “The CAN Bus Protocol Tutorial,” kvaser.com, https://www.kvaser.com/can-protocol-tutorial/, (accessed Nov. 28, 2023).
[7] Texas Instruments, “SN65HVD230DR,” ti.com, https://www.ti.com/lit/ds/symlink/sn65hvd230.pdf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 e.com%252F, (https://www.ti.com/lit/ds/symlink/sn65hvd230.pdf?HQS=dis-dk-null-digikeymode-dsf-pf-null-wwe&ts=1709546681296) (accessed Mar 4, 2024).
[8] u-blox, “NEO-M9N Integration Manual,” u-bloxcom, https://content.u-blox.com/sites/default/files/NEO-M9N_Integrationmanual_UBX-1 9014286.pdf, (https://content.u-blox.com/sites/default/files/NEO-M9N_Integrationmanual_UBX-19014286.pdf) (accessed Nov. 28, 2023).
[9] European Space Agency, “GPS Navigation Message,” gssc.esa.int, https://gssc.esa.int/navipedia/index.php/GPS_Navigation_Message, (accessed 12/6/2023).
[10] Federal Aviation Administration, “Satellite Navigation - Global Positioning System (GPS),” faa.gov,
https://www.faa.gov/about/office_org/headquarters_offices/ato/service_units/techops/navservices/gnss/gps, (https://www.faa.gov/about/office_org/headquarters_offices/ato/service_units/techops/navservices/gnss/gps) (accessed 12/6/2023).
[11] STMicroelectronics, “STM32F0 series Cortex-M0 programming manual,” st.com, https://www.st.com/resource/en/programming_manual/pm0215-stm32f0-series-cor texm0-programming-manual-stmicroelectronics.pdf, (https://www.st.com/resource/en/programming_manual/pm0215-stm32f0-series-cortexm0-programming-manual-stmicroelectronics.pdf) (accessed Mar 4, 2024).
[12] Adafruit, “ST-Link STM8/STM32 v2 Compatible Programmer & Emulator,” adafruit.com, https://www.adafruit.com/product/2548, (accessed Mar 4, 2024).
[13] Silicon Labs, “Serial Wire Debug (SWD), https://community.silabs.com/s/article/serial-wire-debug-swd-x?language=en_US, community.silabs.com, (accessed Mar 4, 2024).

### 4.3.7 Revision Table

TABLE VIII
Subsection 4.2 Revision Table
3/8/2024 | Alexander Gibson: Updated section 4.3.1 with a statement about how the block contributes to the overall system, provided schematic diagrams in section 4.3.2, rewrote section 4.3.3 to discuss the new schematics, updated section 4.3.4 by adding a table label, including new interfaces and their properties, and fixing Vmin and Vmax values due to them being incorrectly switched, updated section 4.3.5 to prove all interfaces of the block, and updated section 4.3.6 with more datasheet links.

1/24/2024 | Alexander Gibson: Added intro paragraph to design section, updated interface names and values to match student portal, and modified interface validation to match changes in design choices.
12/6/2023 | Alexander Gibson: Filled out sections 4.2.1 through 4.2.7

### 4.4 GPS Code

### 4.4.1 Description

The GPS Code block is used by the system to provide the microcontroller code necessary for the GPS hardware block to function correctly. The code works by first configuring the GPS with the correct settings before taking position values at a rate of 5Hz. After each measurement, it sends the data over the CAN bus interface which is then received by the logger module. The code is uploaded to the microcontroller using a Serial Wire Debug interface (SWD) provided by an ST-Link programmer device.

### 4.4.2 Design

This section provides a black box diagram and pseudocode to describe the functionality of the ADC Code block.

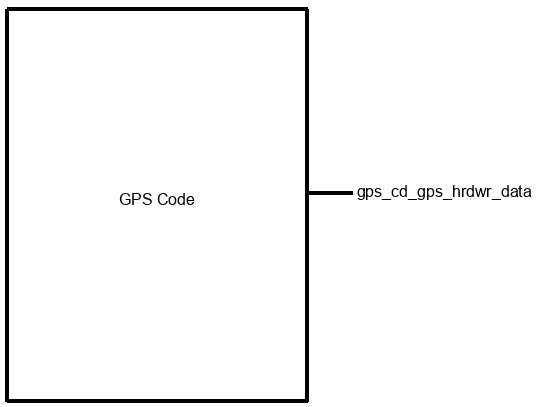
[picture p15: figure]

Fig. 1. Black box image of the GPS Code block

Import libraries.
Bind interrupts for CAN bus peripheral.
Create objects for CAN bus and UART connections. Configure CAN object to use a bitrate of 100Kbps. Reset the GPS using UART communication. Configure the GPS through UART.
Loop
Read GPS position measurement.
Create a transfer frame for CAN communication protocol. Send the transfer frame to the CAN data bus.
Wait 200 ms.
end

Fig. 2. Pseudocode for the GPS Code block

### 4.4.3 General Validation

The GPS Code block needs to be able to take 8-bit or larger position measurements at a rate of 5Hz and send them out over CAN bus. This code also needs to be able to be uploaded to an STM32F072C8T6TR microcontroller through a pin header connection using SWD.

Figure 2 from section 4.4.2 shows how this code will function. By using the embassy framework library, objects can be created for the UART and CAN bus peripherals. These objects are first created by passing the correct pin values for their respective I/O pins, and any necessary interrupts used for their functionality. The CAN object is then configured to communicate at a rate of 100Kbps. According to the datasheet for the GPS, UART protocol is used to read measurements from it [2]. After initializing settings on the GPS, the code infinitely loops by taking GPS measurements and sending them over CAN. It does this by using a 200 ms timer so that measurements can be taken at exactly 5Hz. The loop waits for the timer to complete before sending the read request to the GPS. After receiving the data, it then outputs the data in a CAN transmission frame from the CAN_tx pin on the microcontroller. The timer is then reset and the loop repeats.

### 4.4.4 Interface Validation

Table I
GPS Code Block interface validation table
Interface
Property

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

gps_cd_gps_hrdwr_data : Bi-directional

Messages: Binary code file | Code must be compiled down to machine code to be run on the microcontroller. | Binary instructions stored in flash memory are used to control the microcontroller [3].
Other: Pin header connection | Pin headers were chosen for an easy connection method using an ST-Link programmer. | St-Link connector uses pin connections to program the microcontroller [4].
Protocol: Serial Wire Debug | SWD is used by the ST-Link programmer. | SDW sends a data stream over two wires to program ARM CPUs such as STM32 microcontrollers [5].

### 4.4.5 Verification Process

4. Connect the ST-link programmer between the computer and the pin headers of the gps_cd_gps_hrdwr_data interface.
5. Flash the code onto the microcontroller.
6. Connect the GPS hardware block to the logger block and confirm that the logger is receiving data.

### 4.4.6 References and File Links

[1] Embassy Project Contributors, “embassy_stm::can,” docs.embassy.dev, https://docs.embassy.dev/embassy-stm32/git/stm32f413rh/can/index.html, (accessed Dec. 6, 2023).
[2] u-blox, “NEO-M9N Integration Manual,” u-bloxcom, https://content.u-blox.com/sites/default/files/NEO-M9N_Integrationmanual_UBX-1 9014286.pdf, (https://content.u-blox.com/sites/default/files/NEO-M9N_Integrationmanual_UBX-19014286.pdf) (accessed Nov. 28, 2023).
[3] STMicroelectronics, “STM32F0 series Cortex-M0 programming manual,” st.com, https://www.st.com/resource/en/programming_manual/pm0215-stm32f0-series-cor texm0-programming-manual-stmicroelectronics.pdf, (https://www.st.com/resource/en/programming_manual/pm0215-stm32f0-series-cortexm0-programming-manual-stmicroelectronics.pdf) (accessed Mar 4, 2024).
[4] Adafruit, “ST-Link STM8/STM32 v2 Compatible Programmer & Emulator,” adafruit.com, https://www.adafruit.com/product/2548, (accessed Mar 4, 2024).
[5] Silicon Labs, “Serial Wire Debug (SWD), https://community.silabs.com/s/article/serial-wire-debug-swd-x?language=en_US, community.silabs.com, (accessed Mar 4, 2024).

### 4.4.7 Revision Table

TABLE II
Subsection 4.4 Revision Table
3/8/2024 | Alexander Gibson: Created and filled out sections 4.4.1 - 4.4.7

### 4.5 Mikroe Sensor Hardware Block

### 4.5.1 Description

The Mikroe Sensor Hardware Block features a MikroBUS(TM) connection interface, a microcontroller, a programming interface, a voltage regulator, and a CAN transceiver. This block will allow the system to use any Mikroe Click sensor board with minimal configuration. This will increase the functionality of the system while not requiring the design and assembly of additional custom sensor boards.

The MikroBUS(TM) interface will be used to connect any Mikroe Click sensor board to our system. This will greatly increase the potential functionality of our system by enabling it to use any of the 525 current Mikroe click sensor boards available on Mikroe's website [1]. The firmware for the connected Click Sensor board can be sent to the microcontroller using the programming port. The connected Mikroe Click sensor board can then send data to the microcontroller, which works to update the logger block with the sensor data using CAN bus communication through the CAN transceiver.

### 4.5.2 Design

This block must include a MikroBUS(TM) connection interface for the Mikroe Click Sensor Boards to connect to, an STM32 microcontroller to control the logic, a programming connection so the code from the Mikroe Sensor Code block can be uploaded, a power input port with a voltage regulator to make sure it is powered at the correct level, and a CAN bus transceiver and connector to send data to the logger block. See Figure 1 below for the black box image of this block.

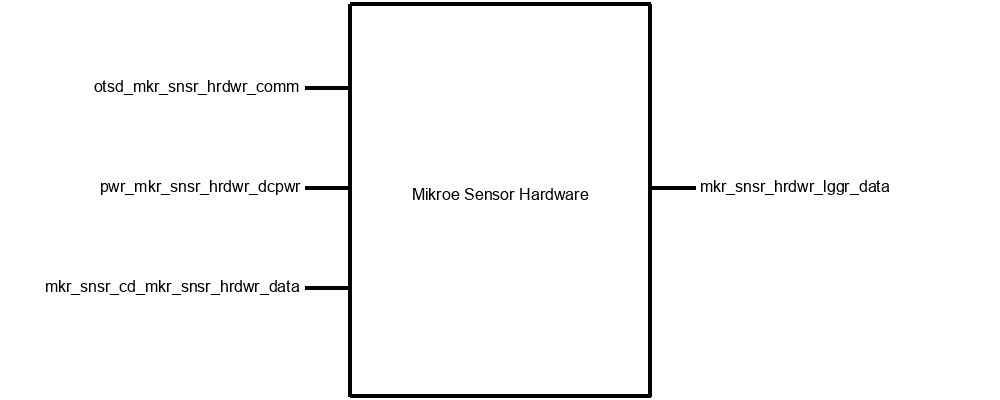
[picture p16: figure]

Fig. 1. Mikroe Sensor Hardware Block black box image

The microcontroller is the heart of this block. The microcontroller communicates with the connected Mikroe Click sensor board via the MikroBUS(TM) connection. Then, it relays the sensor data to the logger block using CAN bus communication.

The microcontroller chosen for our design is an STM32F072C8T6TR. Figure 2 below shows the setup for the microcontroller. The capacitors at the power pins were chosen according to STM32 design guidelines [2], as well as an in-depth YouTube tutorial [3]. The boot and reset pins were also set up according to the mentioned resources. The high-speed external oscillator, ASE-25.000MHZ-L-C-T, on the left of the figure, was set up according to suggestions in its datasheet [4].

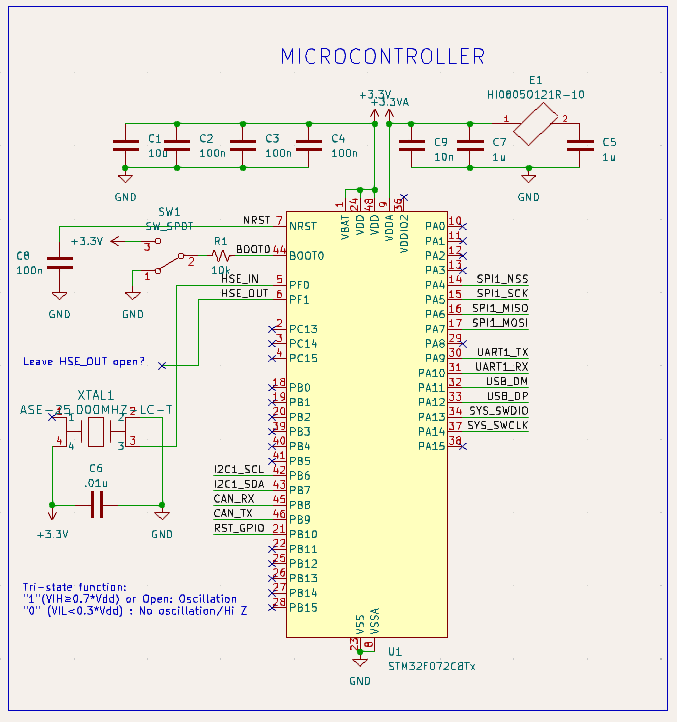
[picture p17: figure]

Fig. 2. Mikroe Sensor Hardware Block Microcontroller Schematic

This block will include a voltage regulator to step the 5V input voltage down to a workable 3.3V for the microcontroller. This voltage regulator will be an LD39050PU33R. Figure 3 below shows the “power” section of the block schematic. The voltage regulator portion of the circuit was created using the application information in the
LD39050PU33R datasheet [5]. We are also using a SP0503BAHTG for TVS protection as seen in figure 3.

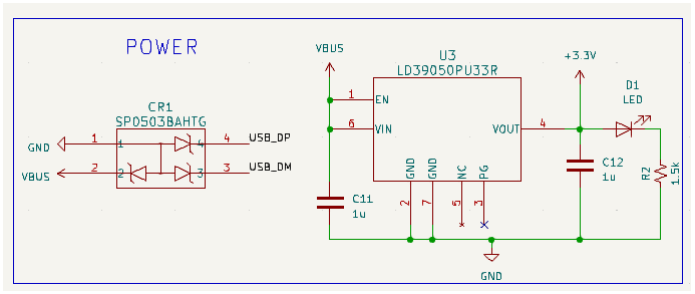
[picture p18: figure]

Fig. 3. Mikroe Sensor Hardware Block Power Schematic

The block will also include a CAN transceiver to transmit and receive data between this block and the logger block through the CAN bus protocol. This transceiver will be an SN65HVD230DR. The CAN transceiver was set up according to the application section of its datasheet [6]. Figure 4 below shows the “CAN” section of the block schematic.

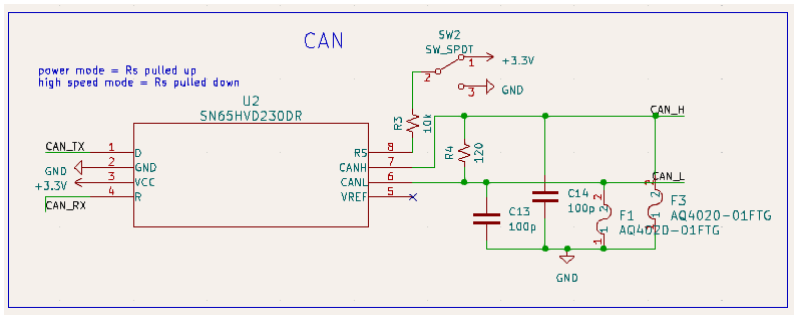
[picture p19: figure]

Fig. 4. Mikroe Sensor Hardware Block CAN Schematic

Finally, figure 5 below shows the “Interfaces/Connectors” section of the schematic. Here can be seen the MikroBUS connector for the Mikroe Click Sensors (otsd_mkr_snsr_hrdwr_comm interface), the Micro-USB connector for power (pwr_mkr_snsr_hrdwr_dcpwr interface), the pin header connection for programming (mkr_snsr_cd_mkr_snsr_hrdwr_data interface), and an RJ45 connector for CAN communication (mkr_snsr_hrdwr_lggr_data interface). Note that power can be supplied through the pin headers or the Micro-USB connector.

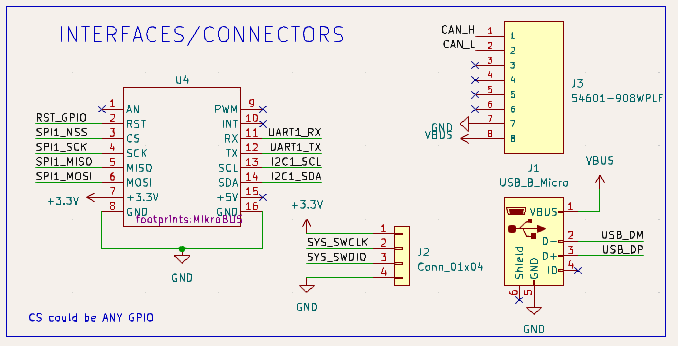
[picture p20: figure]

Fig. 5. Mikroe Sensor Hardware Block Interfaces / Connectors Schematic

### 4.5.3 General Validation

This section will describe why our chosen design details fit the needs of the system as a whole, especially with regard to the block’s function, cost, and engineering time. This section will also include an alternate solution for this block’s design. The overall function of this block is to take sensor data from a Mikroe Click sensor and output that data to the logger block through the CAN bus protocol.

MikroBUS(TM) was chosen as the connection type for external sensors because of the vast amount of possible sensors to choose from, including biometrics, gas, magnetic, motion, optical, pressure, proximity, temperature & humidity, current, force, and inductance sensors [1]. This will allow the project partner and any future users of the system to have access to near-limitless functionality and be able to adapt the system to their specific needs. The project partner also has previous experience with the company and their products and can attest to their support and the ease of use of their products. Finally, the sensors are well documented and most cost under $50, ensuring the system stays operable and affordable.

The specific STM32 microcontroller that will be used for this block, STM32F072C8T6TR, was chosen for its compatibility with the Embassy IDE, which will be used in development, as well as for its favorable input and output capabilities. Some of the capabilities include pins for USB 2.0, SPI, I2C, UART, and CAN communication [7]. Pins for these purposes can also be seen in Figure 2 above. Additionally, the team will be conducting tests using a Mikroe MCU card with a microcontroller very similar to our final choice microcontroller; using such a similar microcontroller for the final design will help ensure a smooth transition from testing to implementation.

The programming interface for the block will utilize a pin header connection. This was chosen because an ST-Link programmer will be used to program the block and the ST-Link programmer uses pin connections [8]. Additionally, this type of interface will be cost-effective, simple to physically implement, and won’t take up much room.

The power interface will use a Micro-USB connector. Using such a common port will help ensure cost-effectiveness and part-availability. We will use Amphenol’s
10118194-0001LF Micro-USB connector for our design [9]. The voltage regulator will be an LD39050PU33R. This was chosen for its favorable characteristics including Input voltage from 1.5V to 5.5V, output voltage from 0.8 V to 4.5 V with 100 mV step, and 500mA guaranteed output current [5]. This regulator is also less than two dollars and comes in a 3mm x 3mm package, ensuring it will keep costs down through both the initial purchase price as well as only requiring minimal space on our PCB. Additionally, it has been successfully utilized on boards that include a microcontroller similar to the one we will use such as the STM32 Nucleo-144 boards [10], which ensures it is a commercially viable option. Our implementation of this regulator can be seen in Figure 3 above.

The CAN transceiver chosen for our design is the SN65HVD230DR. This selection was made due to its advantageous features and performance characteristics including that it operates on a single 3.3V supply, is able to be used for Data Rates up to 1 Mbps, and is low power [6]. Furthermore, this transceiver costs less than three dollars. Finally, we have had a chance to use this specific transceiver while testing our blocks, utilizing a breakout board sourced from Amazon [11]. This experience will allow for seamless integration into our final system, making it an ideal choice for our project's requirements. Our implementation of this transceiver can be seen in Figure 4 above.

One alternate solution for this block would be to use a different, single connection protocol to gather data from a sensor such as SPI, UART, or I2C instead of a MikroBUS(TM) interface. This may allow for a more compact and simpler design that can use sensors beyond those offered by Mikroe. However, this would leave the responsibility of ensuring proper sensor communication and operation with the end-user, complicating the task of connecting external sensors. This would hurt the usability of our system and limit the potential user base to technically savvy individuals. These are unacceptable tradeoffs for our project partner, thus the MikroBUS(TM) connection was chosen.

### 4.5.4 Interface Validation

This section includes a table formatted to show each interface and each interface property relating to the Mikroe Sensor Block, as well as an explanation of why the interface property values were chosen and why the block will work with that value.

TABLE I
Mikroe Sensor Block interface validation table
Interface
Property

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

otsd_mkr_snsr_hrdwr_comm : Input

Datarate: 100kbps or more | According to the MikroBUS(TM) standard specifications, MikroBUS(TM) has three groups of communications pins: SPI, UART, and I2C [12]. 100kbps was chosen as the data rate based on the minimum capabilities of MikroBUS(TM) communication. The exact data rate will depend on the protocol used by the connected Click Sensor Board. | An STM32F072C8T6TR microcontroller will be used for this block. This line of microcontrollers has been proven to work with MikroBUS(TM) interfaces, as shown by Mikroe’s several STM32-based MCU boards designed to work with MikroBUS(TM)-connected Mikroe Click sensors, such as the STM32f413RH MCU board which will be used for testing [13].
Messages: Data from the Mikroe Click sensor board that is connected | This interface must allow communication between a Mikroe Click Sensor board and the Mikroe Sensor Hardware block. | This value will be met by our block because we designed this block to read data from the MikroBUS interface using official STM32 design guidelines [2].
Other: MikroBUS-style Socket | According to the MikroBUS(TM) standard specifications, the standard was created specifically to interface “microcontrollers or microprocessors (mainboards) with integrated circuits and modules (add-on boards)” [12]. Thus, a MikroBUS(TM) interface was chosen. | This value will be met by our block because we will use the official MikroBUS(TM) Standard specifications to implement the socket [12].

mkr_snsr_cd_mkr_snsr_hrdwr_data : Bi-directional

Messages: Binary code file | Code must be compiled down to machine code to be run on the microcontroller. | Binary instructions stored in flash memory are used to control the microcontroller [14].
Other: Pin header connection | Pin headers were chosen for an easy connection method between the block and an ST-Link programmer. | This value will be met because we will use standard pin header spacing and layout in our physical design.
Protocol: Serial Wire Debug | We will use an ST-Link programmer for programming this block. SWD is supported by the ST-Link programmer [8]. | This protocol was chosen because the STM32F072C8T6TR microcontroller can be programmed and debugged using SWD [8].

pwr_mkr_snsr_hrdwr_dcpwr : Input

Inominal: 33mA | This value was chosen based on the nominal current of the microcontroller being used [7] and an estimate of the nominal current that should be needed by the connected Mikroe Sensor board. | This value will be met by our block because we came up with it by using the STM32F072C8T6TR microcontroller’s datasheet [7] and liberal estimates of potential nominal currents required by common Mikroe Sensor boards [1].
Ipeak: 170mA | This value was chosen based on the peak current of the microcontroller being used [7] and an estimate of the peak current that should be needed by the connected Mikroe Sensor board. | This value will be met by our block because we came up with it by using the microcontroller’s datasheet [7] and liberal estimates of potential peak currents required by common Mikroe Sensor boards [1].
Vmax: 5.2V | Ideal input voltage is 5.0V. This value was chosen to allow for some variance without going too far out of range. | This value will be met by our block because the maximum input voltage for the LD39050PU33R voltage regulator is 5.5V [5], exceeding this value.
Vmin: 4.8V | | This value will be met by our block because the LD39050PU33R voltage regulator can output Vin -0.3V, for Vin values down to 1.5V. So even with 4.8V, the regulator will be able to output 3.3V [5].

mkr_snsr_hrdwr_lggr_data : Output

Datarate: 1Kbit/sec CAN bus speed | CAN bus communication protocol allows for a data rate of 1 Kbit/sec [15]. | This value will be met by our block because the SN65HVD230DR CAN transceiver allows for data rates from 0 to 1Mbps, according to Figure 1 of the datasheet [6]. And the STM
Messages: 8 bits wide | CAN bus communication protocol can use 8-bit messages [15]. | This value will be met by our block because the CAN protocol allows for zero to eight bytes of data [15].
Protocol: CAN bus | CAN bus was chosen as the protocol to communicate between the logger block and the Mikroe Sensor Hardware Block because it is well known with good documentation and support, and | The STM32F072C8T6TR microcontroller allows for CAN communication. According to the datasheet, “The CAN is compliant with specifications 2.0A and B (active) with a bit rate up to 1 Mbit/s” [7].

our project partner is familiar with the protocol.

### 4.5.5 Verification Process

1. Connect the power input of the block to a power supply.
2. Connect a Mikroe Click sensor board to the block using the block’s MikroBUS(TM) socket. This proves the otsd_mkr_snsr_hrdwr_comm Other property.
3. Program the microcontroller with the code from the Mikroe Sensor Code block using the block’s pin header connection. This proves the mkr_snsr_cd_mkr_snsr_hrdwr_data Other property.
4. Confirm the protocol of the last operation was USB 2.0 by looking at the code or by seeing that the microcontroller was reading data through its USB 2.0 interface, verifying the mkr_snsr_cd_mkr_snsr_hrdwr_data Protocol property.
5. The correct operation of the block will also confirm the mkr_snsr_cd_mkr_snsr_hrdwr_data Messages property because the only way it would work is if the code was successfully sent to the microcontroller as a binary code file.
6. Use an oscilloscope to view the datarate between the Mikroe Click Sensor and the Mikroe Sensor Hardware block, verifying the otsd_mkr_snsr_hrdwr_comm Datarate property.
7. Attach the block to a Raspberry Pi using a CAN bus connection setup.
8. Confirm communication between the Mikroe Click sensor board and the block, as well as the block and the Pi by looking at the data transferred to the Pi.
9. This covers the mkr_snsr_hrdwr_lggr_data Protocol property and the otsd_mkr_snsr_hrdwr_comm Messages property.
10. Note the data rate between the Mikroe Sensor Hardware block and the logger using an oscilloscope, proving the mkr_snsr_hrdwr_lggr_data Datarate property.
11. Note the message width by viewing transmitted data on the Pi, proving the mkr_snsr_hrdwr_lggr_data Messages property.
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

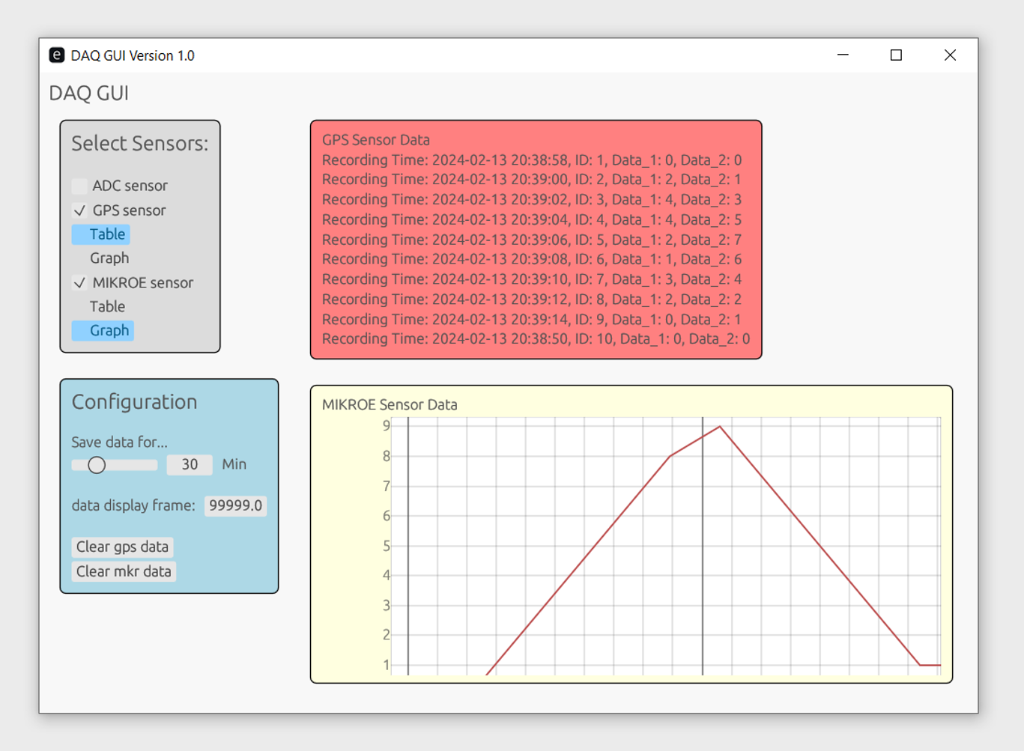
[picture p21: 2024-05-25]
project_gallery/UI.png

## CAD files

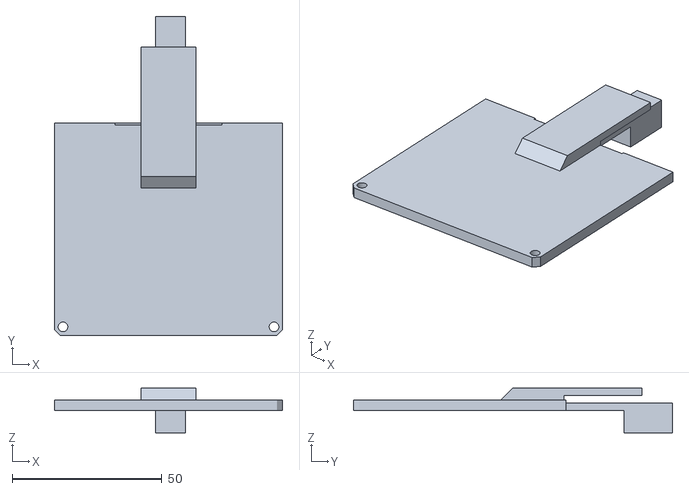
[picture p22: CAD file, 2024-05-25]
enclosure_files/mkr case - Part 3.stl
76.2 x 106.5 x 15.0

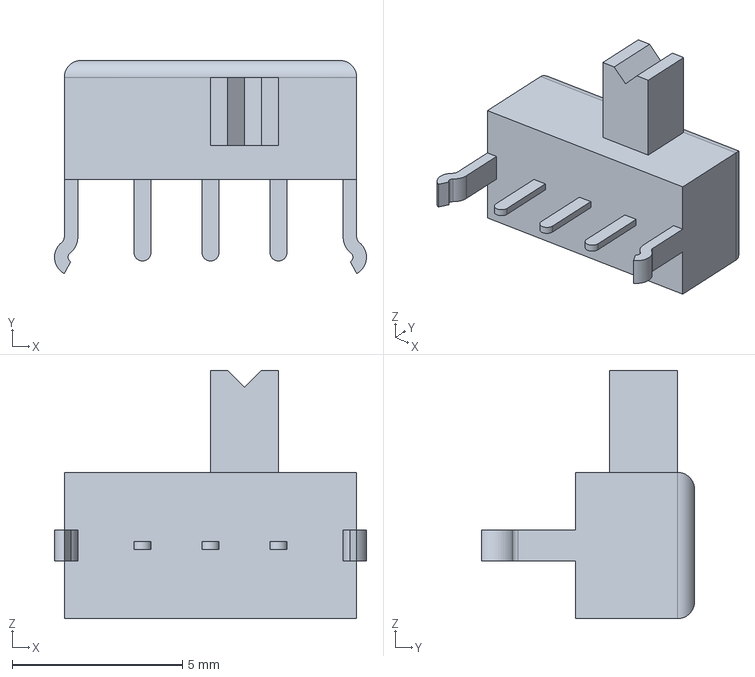
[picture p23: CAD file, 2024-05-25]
pcb_files/ADC_Module/1825232_1/c-1825232-1-b-3d.stp
9.17 x 6.27 x 7.30 mm

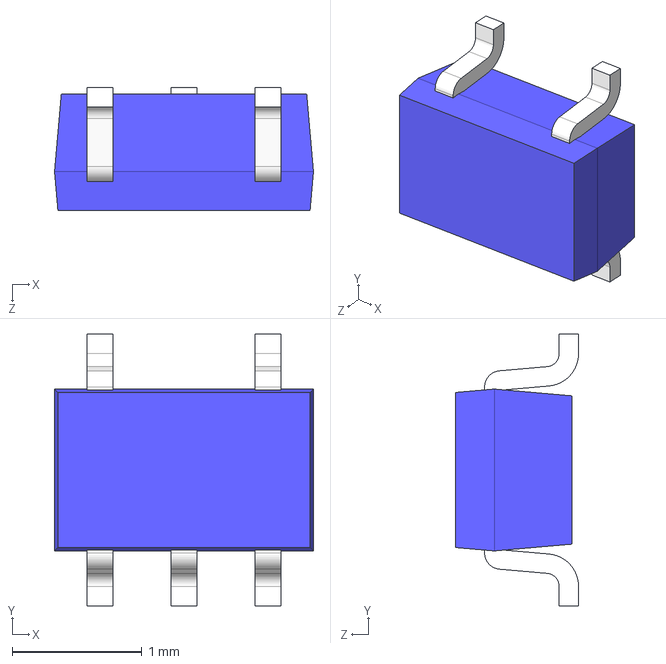
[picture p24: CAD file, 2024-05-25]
pcb_files/ADC_Module/DF5A5_6LFU_TE85L_F/USV.step
2.00 x 2.10 x 0.95 mm

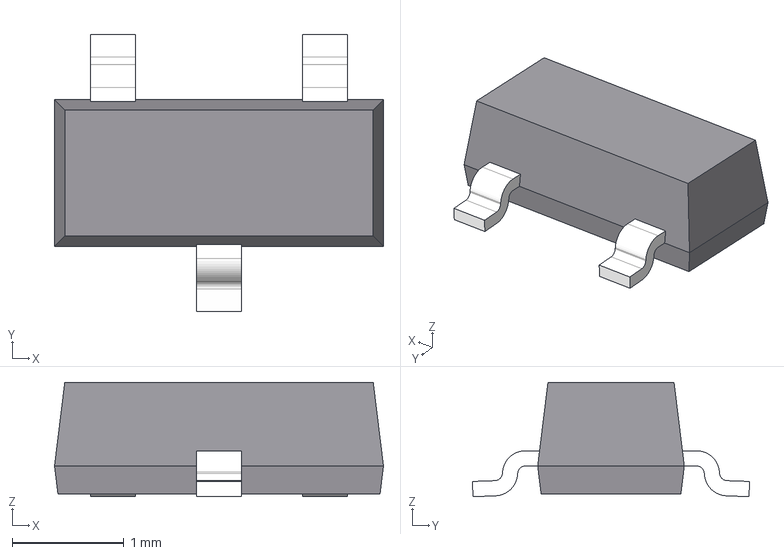
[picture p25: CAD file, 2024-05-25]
pcb_files/ADC_Module/GSOT03C_E3_08/SOT-23_J.stp
2.95 x 2.48 x 1.02 mm

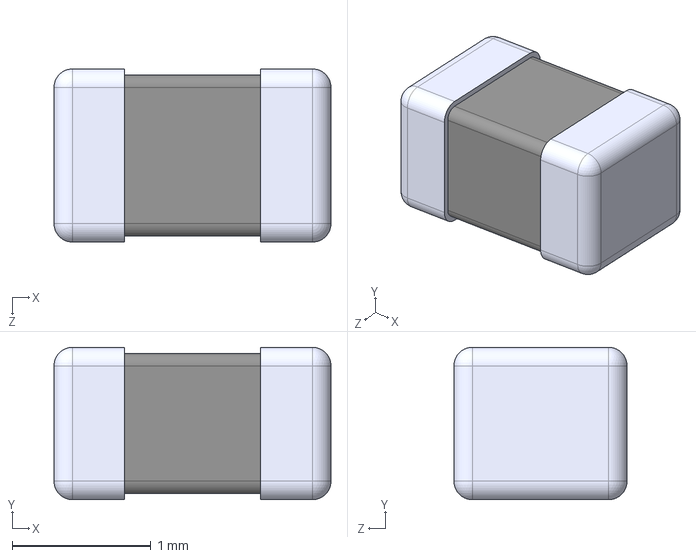
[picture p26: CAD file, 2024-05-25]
pcb_files/ADC_Module/HI0805O121R_10/HI0805O121R-10.step
2.00 x 1.10 x 1.25 mm

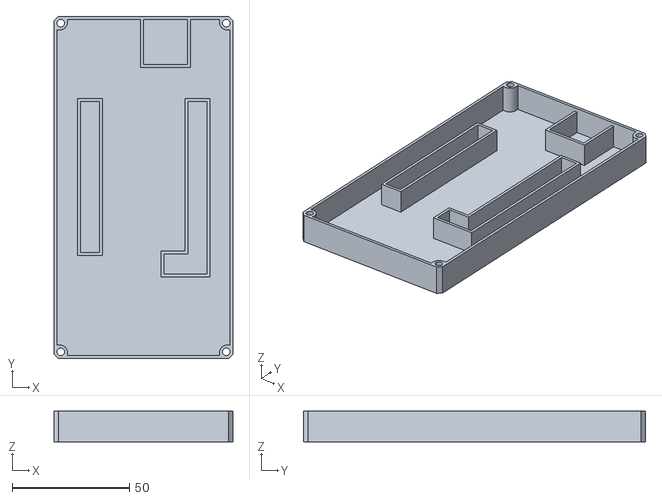
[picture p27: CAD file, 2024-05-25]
enclosure_files/mkr case - Part 1.stl
76.2 x 145.7 x 13.1

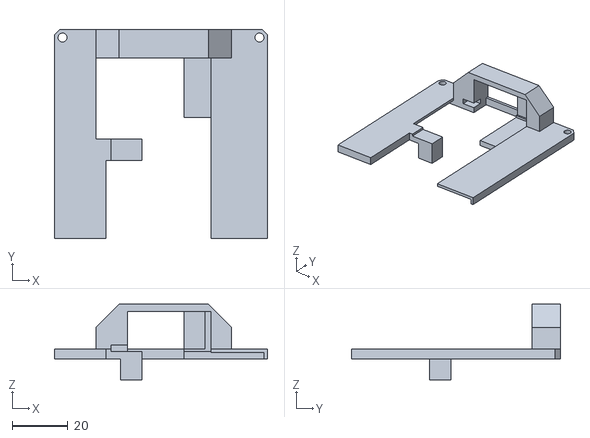
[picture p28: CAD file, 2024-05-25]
enclosure_files/mkr case - Part 4.stl
76.2 x 74.8 x 27.1

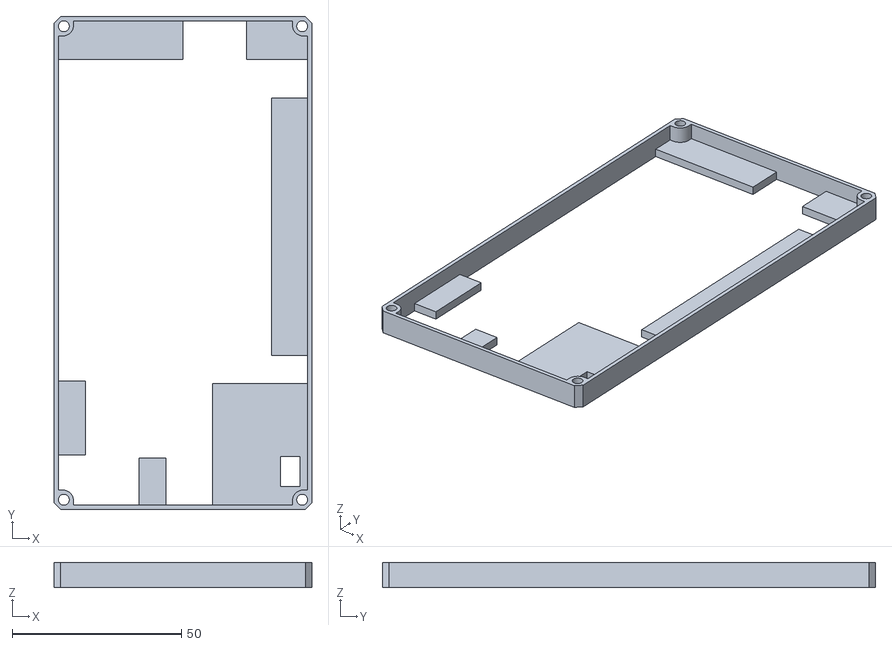
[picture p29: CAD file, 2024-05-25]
enclosure_files/mkr case - Part 2.stl
76.2 x 145.7 x 7.50

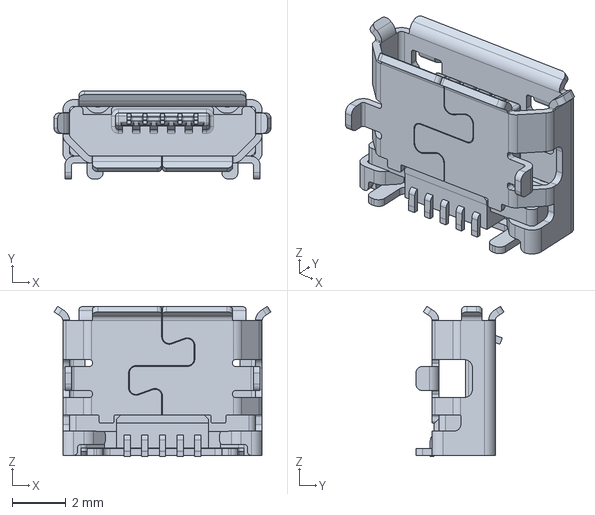
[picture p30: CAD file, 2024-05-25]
pcb_files/ADC_Module/10118194_0001LF/10118194c.stp
8.05 x 3.27 x 5.58 mm

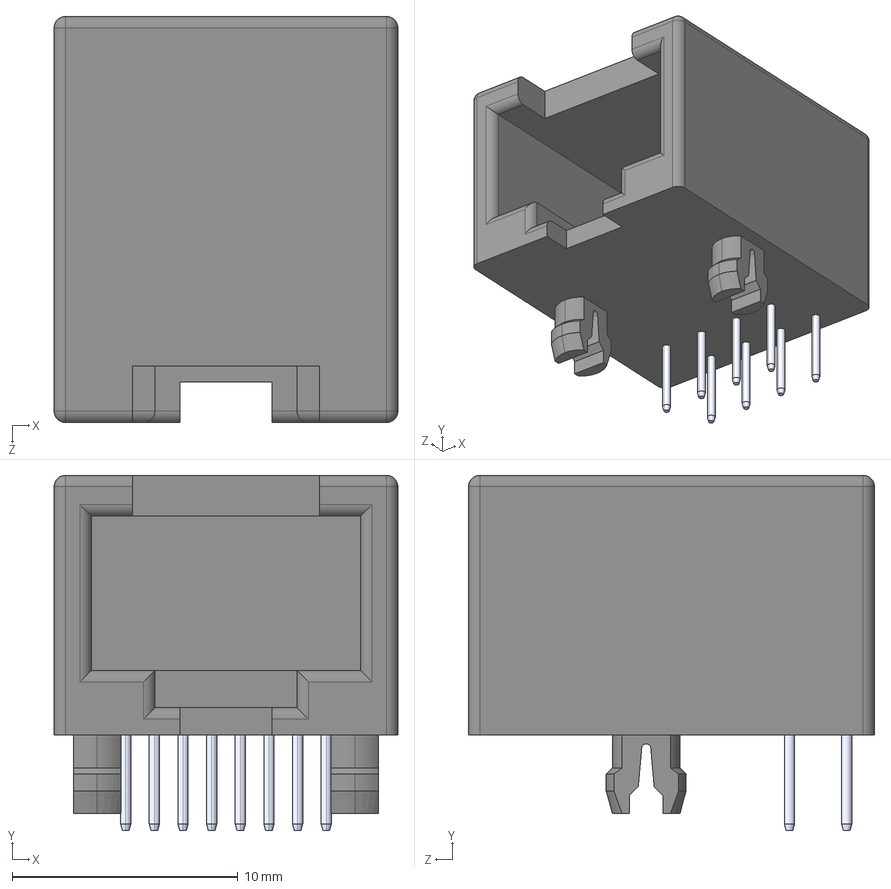
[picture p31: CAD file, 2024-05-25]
pcb_files/ADC_Module/54601_908WPLF/54601-908WPLF.step
15.2 x 15.8 x 18.0 mm

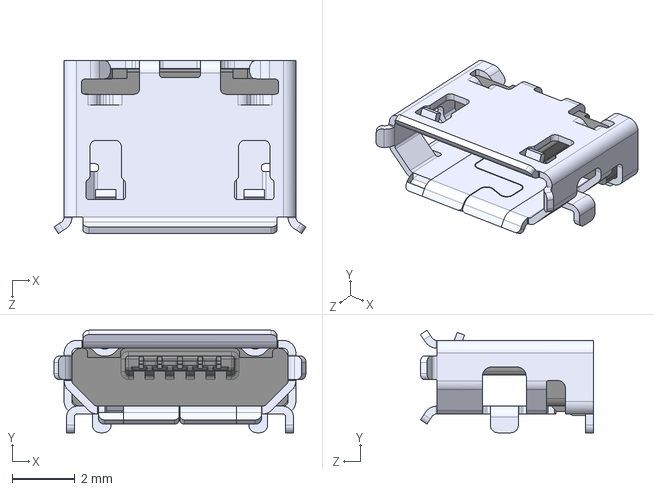
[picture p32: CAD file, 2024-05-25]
pcb_files/ADC_Module/10118194_0001LF/10118194-0001LF.step
8.05 x 3.27 x 5.53 mm

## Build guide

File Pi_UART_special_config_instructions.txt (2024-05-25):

Pi UART special config instructions
This guide goes through how to set up backup UARTs on the Pi for use with a GPS or other sensor module that uses UART.
WARNING: This may cause the CAN Hat to not work properly for some reason

1. Enable UART:
	In Pi terminal:
	sudo raspi-config -> Interface options -> Serial port -> login shell question? NO -> Enable? YES! -> Ok -> reboot

2. Update config to allow UARTS past UART0:
	In the Pi terminal:
	sudo nano /boot/config.txt
	dtoverlay=uart# //add this line at the bottom of the file
	Possibly reboot

3. Check UART functionality:
	In the Pi terminal:
	raspi-gpio funcs //check which GPIOs have UART as alternate functions
	raspi-gpio set [GPIO #s] a[alternate function number that is is GPIO]
		For example: raspi-gpio set 12-13 a4 //enable UART5 (TXD5/RXD5)
	Raspi-gpio get [GPIO #s] //check that the GPIOs are now doing the right function
	ls -l /dev/AMA* //check that device is made. # after AMA tells which UART it is
	//if this doesnt work, maybe try other UARTS, some gave me issues

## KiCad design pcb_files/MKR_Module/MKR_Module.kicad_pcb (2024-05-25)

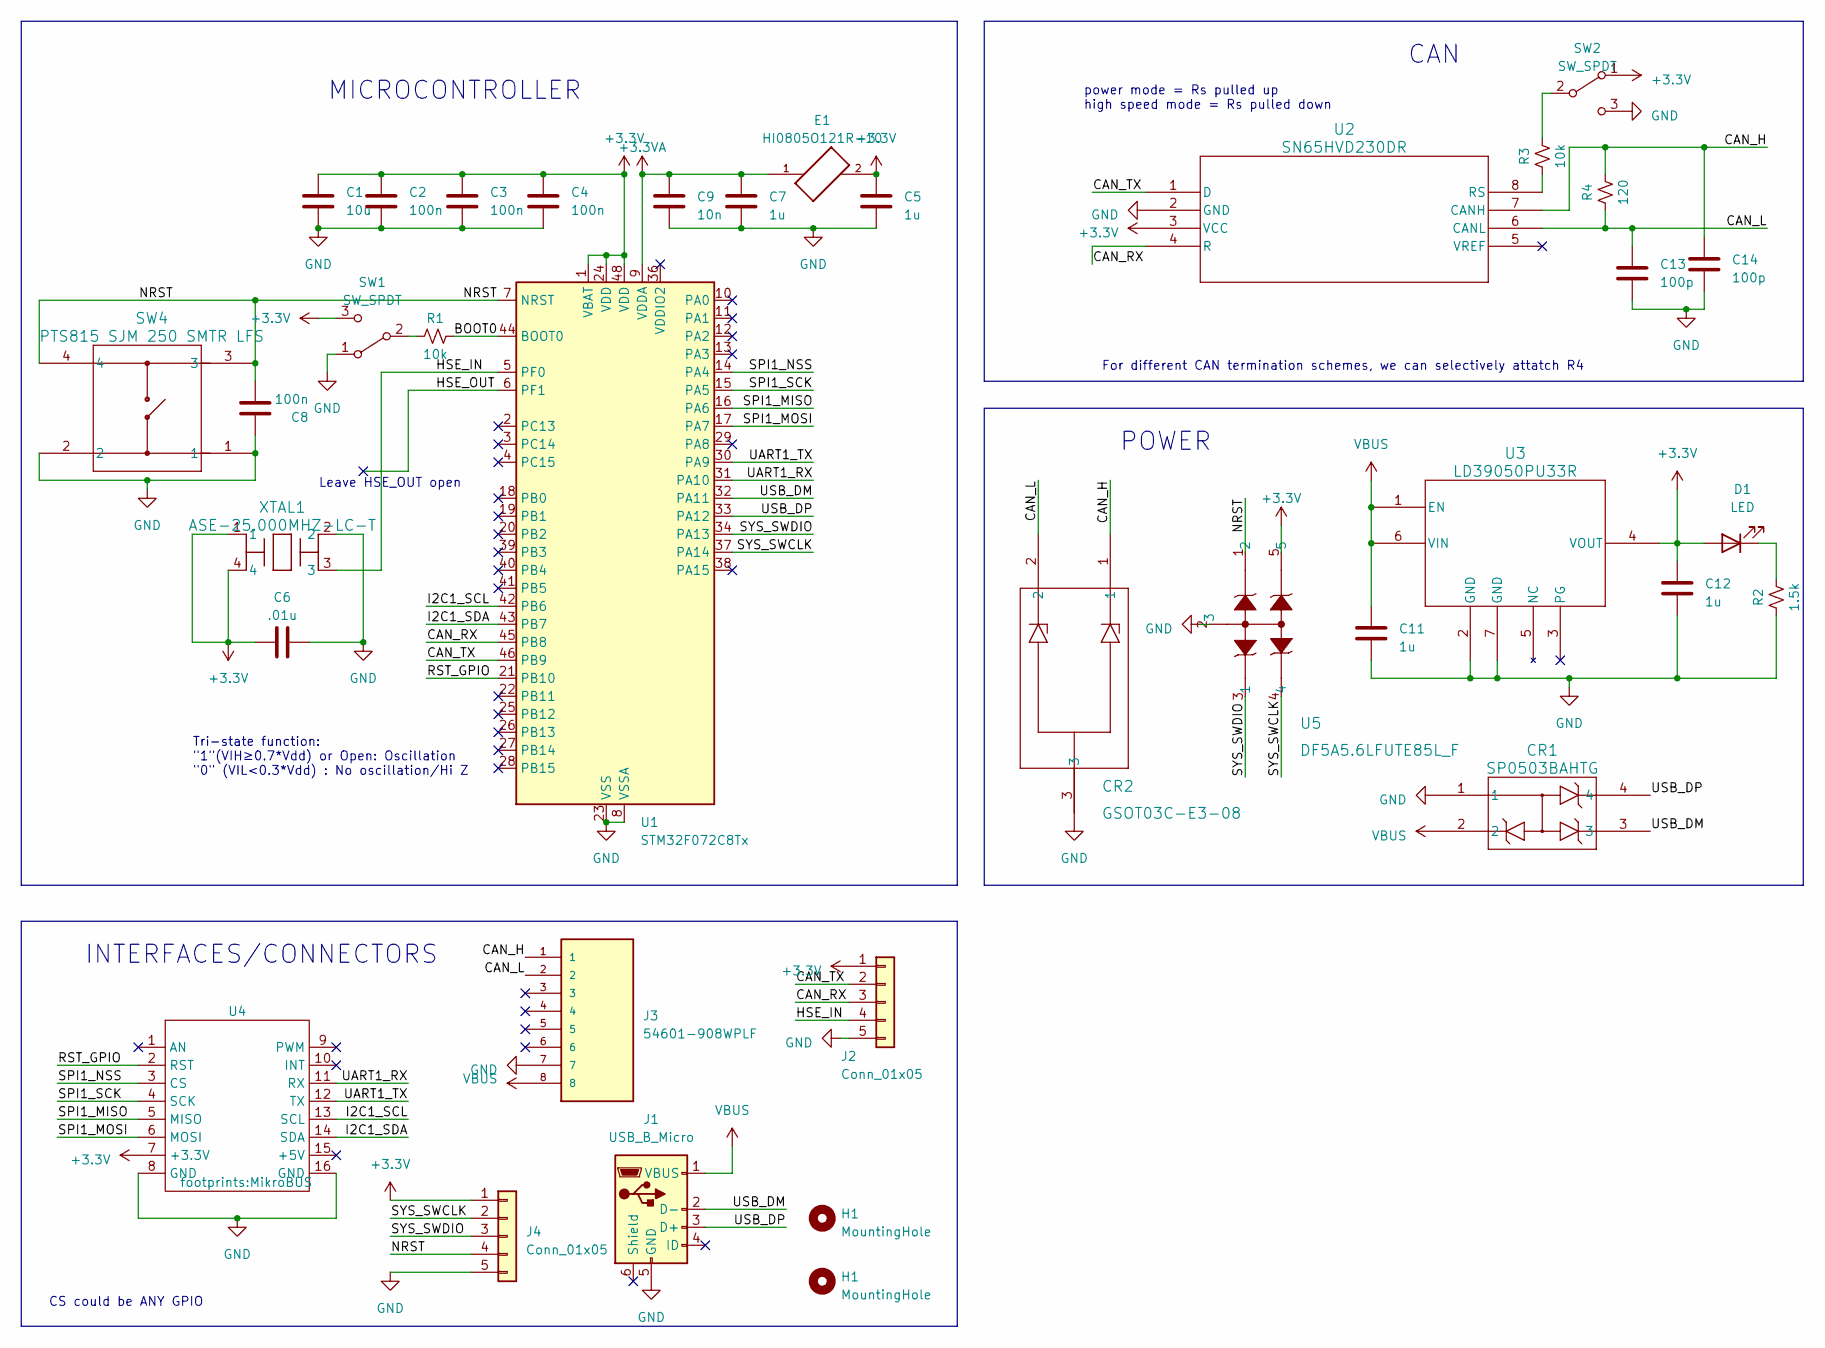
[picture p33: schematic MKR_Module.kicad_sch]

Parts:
C1: 10u; R_0805_2012Metric_Pad1.20x1.40mm_HandSolder
C2, C3, C4, C8: 100n; R_0805_2012Metric_Pad1.20x1.40mm_HandSolder
C5, C7, C11, C12: 1u; R_0805_2012Metric_Pad1.20x1.40mm_HandSolder
C6: .01u; R_0805_2012Metric_Pad1.20x1.40mm_HandSolder
C9: 10n; R_0805_2012Metric_Pad1.20x1.40mm_HandSolder
C13, C14: 100p; R_0805_2012Metric_Pad1.20x1.40mm_HandSolder
CR1: SP0503BAHTG; TVS-SP05_LTF-L
CR2: GSOT03C-E3-08; SOT_03C-E3-08_VIS
D1: LED; R_0805_2012Metric_Pad1.20x1.40mm_HandSolder
E1: HI0805O121R-10; FB_HI0805O121R-10
H1: MountingHole; MountingHole_2.5mm; Digikey Link N/A
J1: USB_B_Micro; AMPHENOL_10118194-0001LF
J2, J4: Conn_01x05; PinHeader_1x05_P2.54mm_Vertical
J3: 54601-908WPLF; AMPHENOL_54601-908WPLF; PARTREV F
R1, R3: 10k; R_0805_2012Metric_Pad1.20x1.40mm_HandSolder
R2: 1.5k; R_0805_2012Metric_Pad1.20x1.40mm_HandSolder
R4: 120; R_0805_2012Metric_Pad1.20x1.40mm_HandSolder
SW1, SW2: SW_SPDT; 1825232-1_TEC
SW4: PTS815 SJM 250 SMTR LFS; SW4_PTS815 SJM 250 SMTR LFS_CNK
U1: STM32F072C8Tx; LQFP-48_7x7mm_P0.5mm
U2: SN65HVD230DR; D8-L
U3: LD39050PU33R; DFN6_3X3_STM-L
U4: MikroBUS
U5: DF5A5.6LFUTE85L_F; SOT-353 USV_TOS
XTAL1: ASE-25.000MHZ-LC-T; CHIP_ASE-24_ABR-L

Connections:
+3.3V: C1.1, C2.1, C3.1, C4.1, C5.1, C6.2, C12.1, D1.2 (A), E1.2, J2.1, J4.1, SW1.3 (C), SW2.1 (A), U1.1 (VBAT), U1.24 (VDD), U1.48 (VDD), U2.3 (VCC), U3.4 (VOUT), U4.7 (+3.3V), U5.5, XTAL1.1, XTAL1.4
+3.3VA: C7.1, C9.1, E1.1, U1.9 (VDDA)
/BOOT0: R1.2, U1.44 (BOOT0)
/CAN_H: C14.1, CR2.1, J3.1, R4.2, U2.7 (CANH)
/CAN_L: C13.1, CR2.2, J3.2, R4.1, U2.6 (CANL)
/CAN_RX: J2.3, U1.45 (PB8), U2.4 (R)
/CAN_TX: J2.2, U1.46 (PB9), U2.1 (D)
/HSE_IN: J2.4, U1.5 (PF0), XTAL1.3
/HSE_OUT: U1.6 (PF1)
/I2C1_SCL: U1.42 (PB6), U4.13 (SCL)
/I2C1_SDA: U1.43 (PB7), U4.14 (SDA)
/NRST: C8.2, J4.4, SW4.3, SW4.4, U1.7 (NRST), U5.1 (2)
/RST_GPIO: U1.21 (PB10), U4.2 (RST)
/SPI1_MISO: U1.16 (PA6), U4.5 (MISO)
/SPI1_MOSI: U1.17 (PA7), U4.6 (MOSI)
/SPI1_NSS: U1.14 (PA4), U4.3 (CS)
/SPI1_SCK: U1.15 (PA5), U4.4 (SCK)
/SYS_SWCLK: J4.2, U1.37 (PA14), U5.4
/SYS_SWDIO: J4.3, U1.34 (PA13), U5.3 (1)
/UART1_RX: U1.31 (PA10), U4.11 (RX)
/UART1_TX: U1.30 (PA9), U4.12 (TX)
/USB_DM: CR1.3, J1.2 (D-), U1.32 (PA11)
/USB_DP: CR1.4, J1.3 (D+), U1.33 (PA12)
GND: C1.2, C2.2, C3.2, C4.2, C5.2, C6.1, C7.2, C8.1, C9.2, C11.2, C12.2, C13.2, C14.2, CR1.1, CR2.3, J1.5 (GND), J2.5, J3.7, J4.5, R2.1, SW1.1 (A), SW2.3 (C), SW4.1, SW4.2, U1.8 (VSSA), U1.23 (VSS), U1.35 (VSS), U1.47 (VSS), U2.2 (GND), U3.2 (GND), U3.7 (GND), U4.8 (GND), U4.16 (GND), U5.2 (3), XTAL1.2
unnamed: D1.1 (K), R2.2
unnamed: R1.1, SW1.2 (B)
unnamed: R3.2, SW2.2 (B)
unnamed: R3.1, U2.8 (RS)
VBUS: C11.1, CR1.2, J1.1 (VBUS), J3.8, U3.1 (EN), U3.6 (VIN)

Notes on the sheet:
POWER
CAN
power mode = Rs pulled up high speed mode = Rs pulled down
For different CAN termination schemes, we can selectively attatch R4
MICROCONTROLLER
Leave HSE_OUT open
INTERFACES/CONNECTORS
Tri-state function: "1"(VIH≥0.7*Vdd) or Open: Oscillation "0" (VIL<0.3*Vdd) : No oscillation/Hi Z
CS could be ANY GPIO

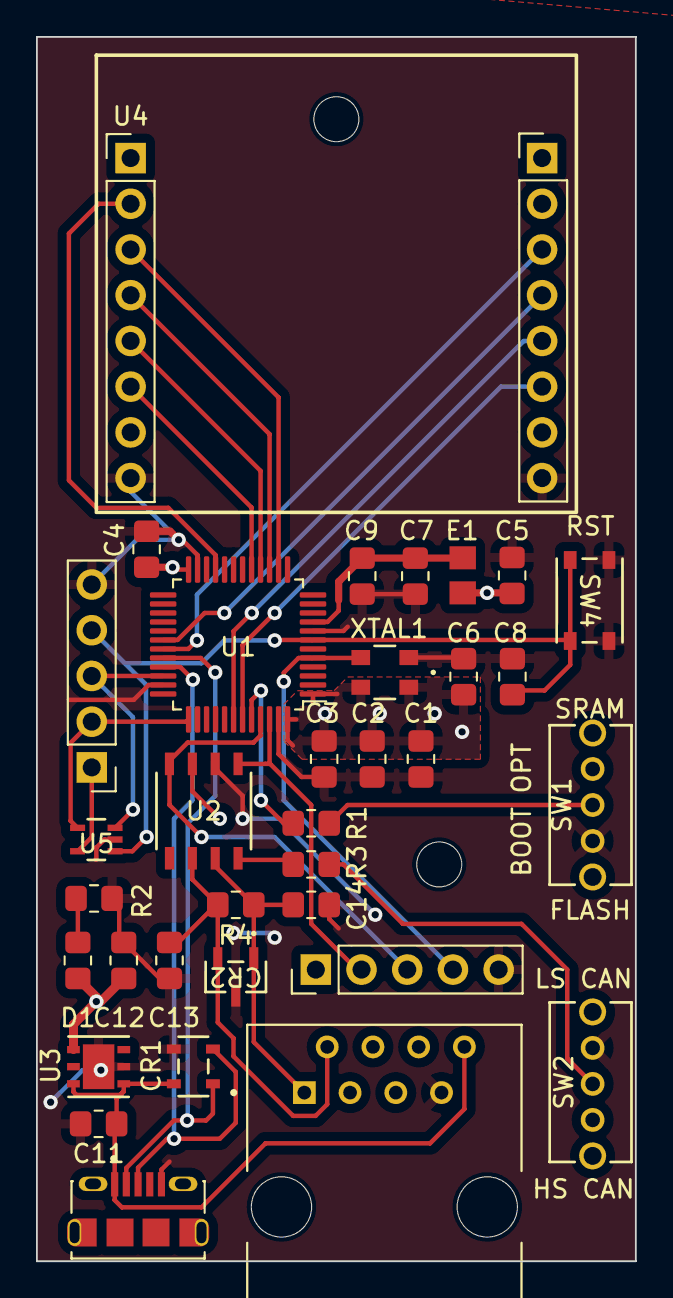
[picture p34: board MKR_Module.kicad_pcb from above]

Board: 2 copper layers, 33.3 x 68.0 mm, 36 parts (0 on the bottom side), 28 nets.

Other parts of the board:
H2: MountingHole; MountingHole_2.5mm

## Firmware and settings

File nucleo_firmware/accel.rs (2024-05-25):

#![no_std]
#![no_main]

//import libraries
use cortex_m::register::apsr::read;
use defmt::*;
use embassy_executor::Spawner;
use embassy_stm32::can::{
    bxcan::{filter::Mask32, Fifo, Frame, Interrupt, StandardId},
    Can, Rx0InterruptHandler, Rx1InterruptHandler, SceInterruptHandler, TxInterruptHandler,
};
use embassy_stm32::dma::NoDma;
use embassy_stm32::gpio::{Level, Output, Speed};
use embassy_stm32::i2c::I2c;
use embassy_stm32::interrupt;
use embassy_stm32::peripherals::CAN1;
use embassy_stm32::spi::{Config, Spi};
use embassy_stm32::time::Hertz;
use embassy_stm32::{bind_interrupts, i2c, peripherals};

use embassy_time::{Duration, Timer};
use embedded_hal::spi;
use {defmt_rtt as _, panic_probe as _};

//define address of the accelerometer
const ACCEL_ADDR: u8 = 0x1E;

//bind CAN interrupts
bind_interrupts!(struct Irqs {
    CAN1_RX0 => Rx0InterruptHandler<CAN1>;
    CAN1_RX1 => Rx1InterruptHandler<CAN1>;
    CAN1_SCE => SceInterruptHandler<CAN1>;
    CAN1_TX => TxInterruptHandler<CAN1>;
});

#[embassy_executor::main]
async fn main(_spawner: Spawner) {
    let p = embassy_stm32::init(Default::default());

    //create objects for the led and CAN bus
    let mut led = Output::new(p.PB7, Level::High, Speed::Low);
    let mut can = Can::new(p.CAN1, p.PD0, p.PD1, Irqs);

    //bind interrupts for I2C communication
    bind_interrupts!(struct Irqs2 {
        I2C1_EV => i2c::EventInterruptHandler<peripherals::I2C1>;
        I2C1_ER => i2c::ErrorInterruptHandler<peripherals::I2C1>;
    });

    // setup can
    can.as_mut()
        .modify_filters()
        .enable_bank(0, Fifo::Fifo0, Mask32::accept_all());

    can.as_mut().modify_config().leave_disabled();

    can.set_bitrate(100_000);

    can.enable().await;

    //configure i2c
    let mut i2c = I2c::new(
        p.I2C1,
        p.PB8,
        p.PB9,
        Irqs2,
        NoDma,
        NoDma,
        embassy_stm32::time::Hertz(100000),
        Default::default(),
    );
    // set digital out pins for microcontroller
    let mut reset_pin = Output::new(p.PA4, Level::Low, Speed::Low);

    //initialize data buffers
    let mut data_buffer: [u8; 13] = [0; 13];
    let mut accel_vals: [u8; 2] = [0; 2];

    // define communication commands
    let read_xyz_data: [u8; 1] = [0x33];

    //wait 1 sec
    Timer::after(Duration::from_millis(1000)).await;

    reset_pin.set_high();
    reset_pin.set_low();

    //wait 1 sec
    Timer::after(Duration::from_millis(1000)).await;

    //check that I2C protocol is working correctly
    match i2c.blocking_write_read(ACCEL_ADDR, &[0x0D], &mut data_buffer) {
        Ok(()) => info!("Whoami: {}", data_buffer[0]),
        // Err(Error::Timeout) => error!("Operation timed out"),
        Err(e) => error!("I2c Error: {:?}", e),
    }
    info!("Accel: {:?}", data_buffer);

    //place control register in standby mode
    i2c.blocking_write_read(ACCEL_ADDR, &[0x2A, 0x00], &mut data_buffer);
    //set magnometer to 8x oversampling
    i2c.blocking_write_read(ACCEL_ADDR, &[0x5B, 0x1F], &mut data_buffer);
    //enable magnetic reset after each cycle
    i2c.blocking_write_read(ACCEL_ADDR, &[0x5C, 0x20], &mut data_buffer);
    //set accelerometer to a range of +/-4g
    i2c.blocking_write_read(ACCEL_ADDR, &[0x0E, 0x01], &mut data_buffer);
    //enable sampling
    i2c.blocking_write_read(ACCEL_ADDR, &[0x2A, 0x0D], &mut data_buffer);

    loop {
        //blink led
        led.toggle();

        //read accelerometer and magnetic field values
        i2c.blocking_write_read(ACCEL_ADDR, &[0x00], &mut data_buffer);

        //copy acceleration values to accel_vals buffer
        accel_vals[0] = data_buffer[1];
        accel_vals[1] = data_buffer[2];
        /*         accel_vals[2] = data_buffer[3];
        accel_vals[3] = data_buffer[4];
        accel_vals[4] = data_buffer[5];
        accel_vals[5] = data_buffer[6];*/
        info!("Accel: {:?}", accel_vals);

        // transmit accelerometer data over can
        let tx_frame = Frame::new_data(unwrap!(StandardId::new(300)), accel_vals);
        can.write(&tx_frame).await;
        Timer::after(Duration::from_millis(1000)).await;
    }
}

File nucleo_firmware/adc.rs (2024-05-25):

#![no_std]
#![no_main]

//import libraries
use defmt::*;
use embassy_executor::Spawner;
use embassy_stm32::can::{
    bxcan::{filter::Mask32, Fifo, Frame, StandardId},
    Can, Rx0InterruptHandler, Rx1InterruptHandler, SceInterruptHandler, TxInterruptHandler,
};
use embassy_stm32::dma::NoDma;
use embassy_stm32::gpio::{Level, Output, Speed};
use embassy_stm32::peripherals::CAN1;
use embassy_stm32::spi::{Config, Spi};
use embassy_stm32::time::Hertz;
use embassy_stm32::{bind_interrupts, i2c, peripherals};

use embassy_time::{Duration, Timer};
use embedded_hal::spi;
use {defmt_rtt as _, panic_probe as _};

//bind interrupts for CAN bus communication
bind_interrupts!(struct Irqs {
    CAN1_RX0 => Rx0InterruptHandler<CAN1>;
    CAN1_RX1 => Rx1InterruptHandler<CAN1>;
    CAN1_SCE => SceInterruptHandler<CAN1>;
    CAN1_TX => TxInterruptHandler<CAN1>;
    I2C1_EV => i2c::EventInterruptHandler<peripherals::I2C1>;
});

// spi words
const BIT_MASK_SPI_CMD_READ: u8 = 0x80;
const ACC_REG_DATA_START: u8 = 0x02;

#[embassy_executor::main]
async fn main(_spawner: Spawner) {
    let p = embassy_stm32::init(Default::default());

    //create objects for the led and CAN bus
    let mut led = Output::new(p.PB7, Level::High, Speed::Low);
    let mut can = Can::new(p.CAN1, p.PD0, p.PD1, Irqs);

    //setup can
    can.as_mut()
        .modify_filters()
        .enable_bank(0, Fifo::Fifo0, Mask32::accept_all());

    can.as_mut().modify_config().leave_disabled();

    can.set_bitrate(100_000);

    can.enable().await;

    // configure spi
    let mut spi_config = Config::default();
    spi_config.frequency = Hertz(100_000);
    spi_config.mode = spi::MODE_3;
    let mut spi = Spi::new(p.SPI1, p.PA5, p.PB5, p.PA6, NoDma, NoDma, spi_config);

    // set digital out pins for microcontroller
    let mut accel_active = Output::new(p.PD15, Level::High, Speed::Low);

    //initialize data buffer for SPI values
    let mut data_buffer: [u8; 3] = [0; 3];

    // define communication commands
    let read_request: [u8; 1] = [0x42];
    let read_control: [u8; 1] = [0x08 | 0x40];
    let config_0: [u8; 3] = [0x19, 0x00, 0x78];
    let reset: [u8; 8] = [0xFF; 8];

    //reset the ADC
    accel_active.set_low();
    spi.blocking_write(&reset).unwrap();
    accel_active.set_high();

    //wait 1 sec
    Timer::after(Duration::from_millis(1000)).await;

    //configure ADC to use Analog Vdd as reference
    accel_active.set_low();
    spi.blocking_write(&config_0).unwrap();
    accel_active.set_high();

    //wait 1 sec
    Timer::after(Duration::from_millis(1000)).await;

    //read setting register
    accel_active.set_low();
    spi.blocking_write(&read_control).unwrap();
    spi.blocking_read(&mut data_buffer).unwrap();
    accel_active.set_high();

    // info!("Accel: {:?}", data_buffer);

    loop {
        //blink led
        led.toggle();

        // read ADC data over spi
        accel_active.set_low();
        spi.blocking_write(&read_request).unwrap();
        spi.blocking_read(&mut data_buffer).unwrap();
        accel_active.set_high();

        // write ADC data to console
        info!("Accel: {:?}", data_buffer);

        // transmit ADC data over can
        let tx_frame = Frame::new_data(unwrap!(StandardId::new(123)), data_buffer);
        can.write(&tx_frame).await;
        Timer::after(Duration::from_millis(1000)).await;
    }
}
